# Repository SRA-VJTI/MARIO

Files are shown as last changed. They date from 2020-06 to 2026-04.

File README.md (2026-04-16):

# MARIO WORKSHOP 2.4








*MARIO* abbreviation for *Manipulator on ROS Based Input Output* is a bot with 3 Degree of Freedom. It consists of two SG90 micro servo and one MG995 metal gear servo motor. The servo motors are placed on base, elbow and shoulder enabling it with 3 Degrees of Freedom.

Given below are instructions for ROS2-Humble and micro-ROS installations. For ROS1 and Rosserial based MARIO, refer to the [following instructions](https://github.com/SRA-VJTI/MARIO/tree/noetic).

## Sneak Peek 

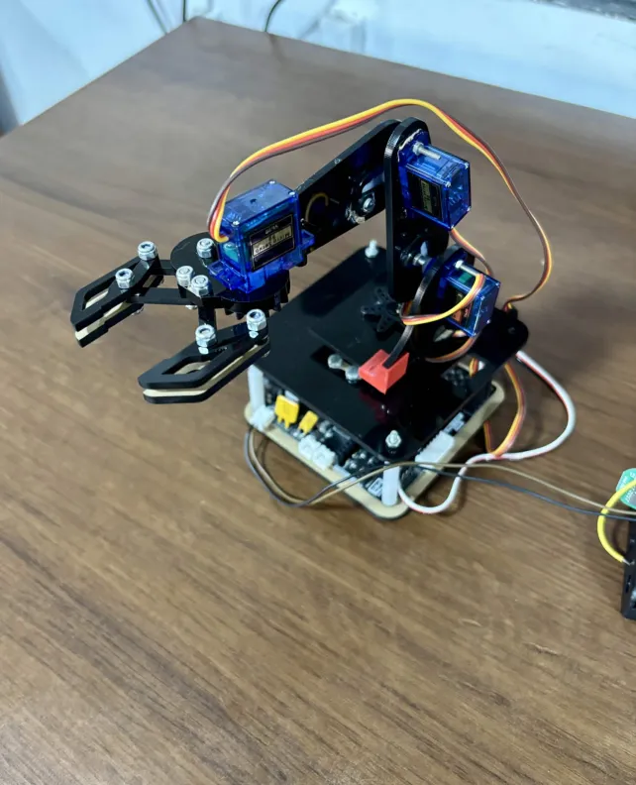
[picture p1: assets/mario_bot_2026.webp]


### Working of the Mario Bot

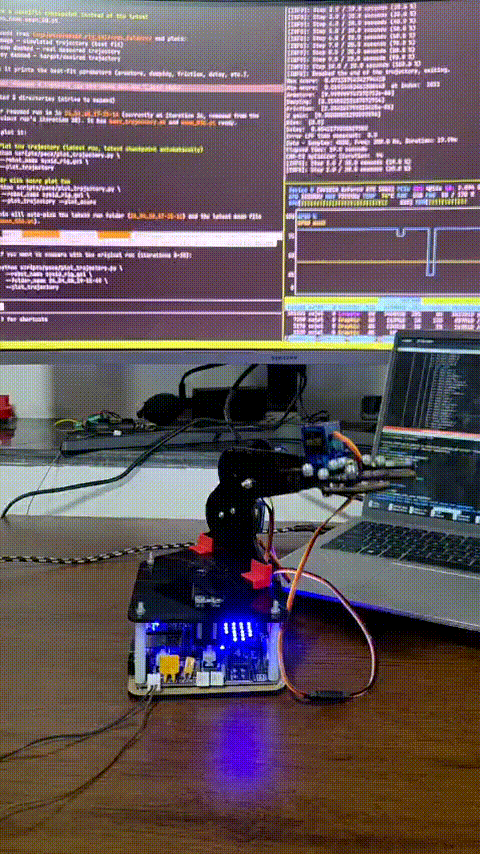
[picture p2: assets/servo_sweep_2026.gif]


### Mario bot simulated using Gazebo

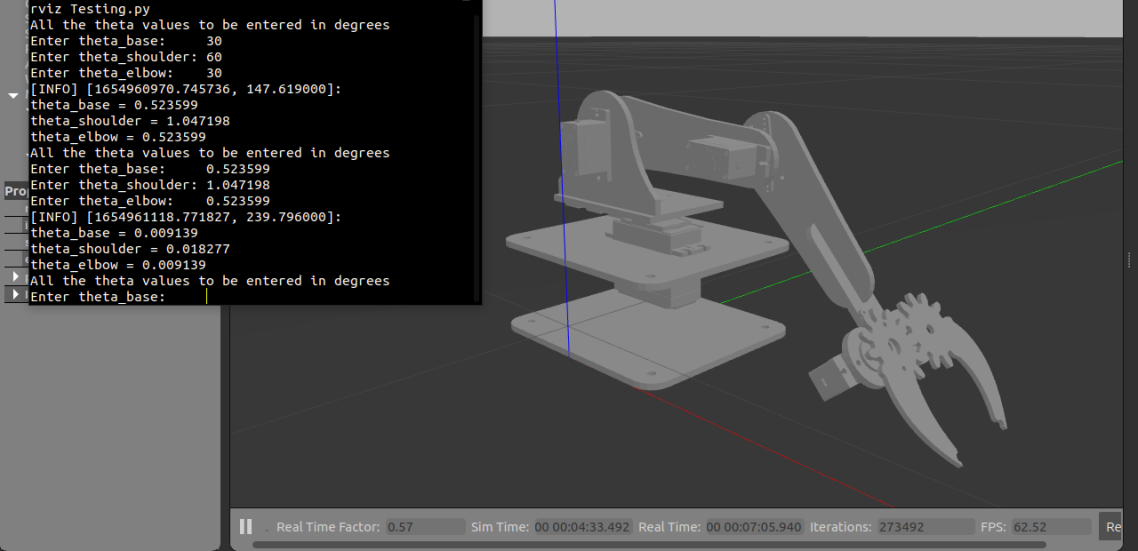
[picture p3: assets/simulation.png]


### Mario bot simulated using Mujoco

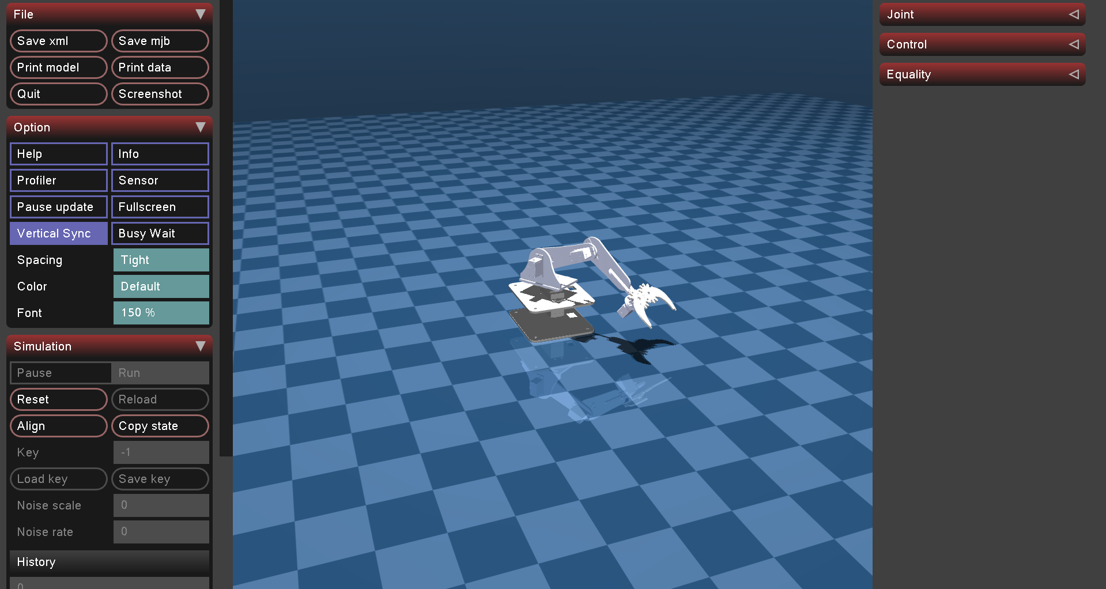
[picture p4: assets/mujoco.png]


## File Structure 
    ├── 1_chatter_listener                        # talker and listener script to understand the nodes and communications in ROS
    ├── 2_simulation_dh                           # simulation of DH parameters
    ├── 3_simulation_rviz                         # simulation of MARIO bot on rviz
    ├── 4_simulation_gazebo                       # simulation of MARIO bot on gazebo
    ├── 5_simulation_mujoco                       # simulation of MARIO bot on mujoco
    ├── assets                                    # contains necessary gifs, images
    ├── firmware                                  # contains ESP-IDF examples for controlling servo motors and micro-ROS
    │   ├── 1_servo_set_ninety                       # example in ESP-IDF to set angles of all servo motor zero
    │   ├── 2_servo_sweep                         # example in ESP-IDF to set variable angles in servo motor
    │   ├── 3_microros_rviz                       # example in ESP-IDF to interface with rviz environment as well as ESP32
    │   ├── 4_microros_gazebo_mujoco                     # example in ESP-IDF to interface with gazebo environment as well as ESP32
    │   ├── 5_servo_test_webserver                # example in ESP-IDF to set angles of servo over the webserver interface
    │   └── components                            # contains all the dependencies required for the above examples
    │       ├── micro_ros_espidf_component        # library to interface between micro-ROS environment and ESP32
    │       └── sra-board-component               # library to interface with SRA board
    ├── LICENSE
    └── README.md 

## Kinematics
* MARIO workshop aims to provide the basic knowledge about the DH parameters, forward kinematics , inverse kinematics.
  * DH Parameters :- Denavit–Hartenberg parameters (also called DH parameters) are the four parameters associated with a particular convention for attaching reference frames to the links of a spatial kinematic chain, or robot manipulator
  * Forward Kinematics :- Forward kinematics refers to the use of the kinematic equations of a robot to compute the position of the end-effector from specified values for the joint parameters. The kinematics equations of the robot are used in robotics, computer games, and animation.
  * Inverse Kinematics :- inverse kinematics is the mathematical process of calculating the variable joint parameters needed to place the end of a kinematic chain, such as a robot manipulator or animation character's skeleton, in a given position and orientation relative to the start of the chain.

## ROS-2 
ROS2 is the ultimate toolkit for robotics enthusiasts and professionals alike. Seamlessly integrating hardware and software, ROS2 streamlines development workflows, accelerates prototyping, and enables rapid iteration. With its modular architecture and extensive library of reusable components, ROS2 simplifies the creation of complex robotics projects, from autonomous drones to collaborative robot arms. 

## Publisher and Subscriber
Publish/Subscribe is a messaging pattern that aims to decouple the sending (Publisher) and receiving (Subscriber) party. A real world example could be a sport mobile app that shows you up-to-date information of a particular football game you're interested in. In this case you are the subscriber, as you express interest in this specific game. On the other side sits the publisher, which is an online reporter that feeds a system with the actual match data.
This system, which is often referred as the message broker brings the two parties together by sending the new data to all interested subscribers.

While ROS2 works on the same system, this system is also used in various other libraries like MQTT.

# MICRO-ROS
micro-ROS is a robotic framework targeting embedded and deep-embedded robot components with extremely constrained computational resources. These devices have special characteristics: a minimum real-time operating system or no operating system, battery-powered, wireless low bandwidth connections, and intermittent operation with sleep periods.

## ESP-IDF
ESP-IDF is the development framework for Espressif SoCs.The [SRA Board](https://github.com/SRA-VJTI/sra-board-hardware-design) uses ESP32 as microcontroller, hence ESPIDF is required
to code the ESP32. Examples included inside firmware directory has been written in ESPIDF version 5.1 .

## Installation of ROS2 and other dependencies 

- Copy and execute the following command in your bash terminal 
```bash
wget -O - https://raw.githubusercontent.com/SRA-VJTI/MARIO/humble/linux_installations.sh | bash
```
- As an alternative, you can also install the required packages on your local machine by following the instructions below.

  - Clone SRA-VJTI's MARIO repository on your system
  ```bash 
  git clone --recursive https://github.com/SRA-VJTI/MARIO.git
  ```
  - Change terminal directory inside the cloned repository
  ```bash
  cd MARIO/
  ```
  - Run the installation script
  ```bash 
  ./linux_installations.sh
  ```

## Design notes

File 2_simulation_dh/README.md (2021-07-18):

## Steps to run the demo in RViz 
We will be running the visualization DH-parameters in RViz.
* First we will be installing the joint_state_publishers and the ros_control for ros-noetic by the following commands

```
sudo apt-get install -y joint-state-publisher
sudo apt-get install ros-noetic-gazebo-ros-pkgs ros-noetic-gazebo-ros-control
```

*  Run the launch file
```
  roslaunch simulation_dh dh_transformation_visualization.launch    
```

<p align="center">
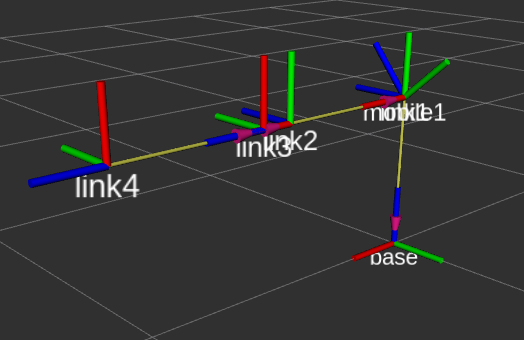
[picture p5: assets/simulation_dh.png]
  
</p>

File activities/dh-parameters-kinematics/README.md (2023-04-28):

# Assignment Day 3

Q.1. Make axes according to the rules given in the DH-parameters for the following end-effectors and bots

Identify the joints and axes in the following bot

Your answer should specify the following parameters:

* Number of joints
* Degrees of freedom
* Types of Joints
* Name all the links starting from base link => search what is ground link
* **Transformation Matrix** from **base to link1 only** => take reference from the DH-parameter’s PPT
* Bonus points if you define your own way of defining DH-parameters 😉

MARIO

```
Note: The lower most link is immovable constraining the workspace of the bot in a single plane
```

Q.2. For the following Robotic arm diagram, Find the DH parameters and the final transformation matrix through Forward Kinematics.



Want a hint ?

`
→ revise ppt (Steps to calculate DH parameter and a particular equation in ppt)
`

Want more hints ?

`→ Ask your seniors :)`

All the best :-)

<!--Q.1. by Alqama and 2 by Chinmay
  SRA-VJTI/MARIO
  Licences for this readme is being transfered solely to the organisation of SRA-VJTI-->

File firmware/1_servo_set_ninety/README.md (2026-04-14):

# Servo Set Ninety

This example demonstrates how to set all servos to 90 degrees for ease of assembly.

## Prerequisites

- ESP-IDF development environment installed and configured
- ESP32 development board
- USB cable for flashing

## Building and Flashing

1. Navigate to the project directory:
   ```bash
   cd ros2_ws_firmware/1_servo_set_ninety
   ```

2. Source the ESP-IDF environment (if not already done):
   ```bash
   # Option 1
   get_idf

   # Option 2
   source . ./esp/esp-idf/export.sh
   ```

3. Build the project:
   ```bash
   idf.py build
   ```

4. Flash to ESP32:
   ```bash
   idf.py -p PORT flash
   ```
   Replace `PORT` with your ESP32's serial port (e.g., `/dev/ttyUSB0` on Linux or `COM3` on Windows)

## Troubleshooting

If you encounter a `cmake flash error`, try the following:

1. Grant permissions to the serial port:
   ```bash
   sudo chmod 777 /dev/ttyUSB0   # Replace with your port
   ```

2. Flash again:
   ```bash
   idf.py -p PORT flash

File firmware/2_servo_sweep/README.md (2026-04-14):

# Servo Sweep Demo

## Overview
This project demonstrates controlling three servos to perform synchronized sweep motions on an ESP32. Each servo moves through different angles in a coordinated pattern.

## Prerequisites
- ESP32 development board
- 3 servo motors connected
- ESP-IDF development environment
- USB cable for flashing

## Hardware Setup
- Ensure all three servos are properly connected to the ESP32
- Check power supply is adequate for all servos
- Verify servo signal pins are connected to correct GPIO pins

## Building and Flashing

1. Navigate to the project directory:
   ```bash
   cd ros2_ws_firmware/2_servo_sweep
   ```

2. Source the ESP-IDF environment:
   ```bash
   # Option 1
   get_idf

   # Option 2
   source $IDF_PATH/export.sh
   ```

3. Build the project:
   ```bash
   idf.py build
   ```

4. Flash to ESP32:
   ```bash
   idf.py -p PORT flash
   ```
   Replace `PORT` with your ESP32's serial port (e.g., `/dev/ttyUSB0` on Linux or `COM3` on Windows)

## Troubleshooting

If you encounter a `cmake flash error`:

1. Set port permissions:
   ```bash
   sudo chmod 777 /dev/ttyUSB0   # Replace with your port
   ```

2. Try flashing again:
   ```bash
   idf.py -p PORT flash
   ```

## Demo

Servo Sweep Demo

## Features
- Synchronized movement of three servo motors
- Smooth sweep motion implementation
- Configurable angle ranges for each servo
- Adjustable sweep speed

## Safety Notes
- Ensure servos are mounted securely
- Keep movement area clear of obstacles
- Monitor servo temperature during extended operation

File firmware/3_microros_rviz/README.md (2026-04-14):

# Micro-ROS with RViz Integration

## Overview
This project demonstrates the integration of ESP32 with RViz using micro-ROS, allowing real-time visualization and control of a robotic manipulator.

## Prerequisites
- ROS 2 installed and configured
- ROS 2 workspace with micro-ROS agent built (`ros2_ws`)
- ESP-IDF development environment
- RViz
- WiFi connection
- `net-tools` package (for network configuration)

## Option 1: WiFi Network

### 1. Start Micro-ROS Agent

Start the micro-ROS agent:
```bash
cd ros2_ws
source install/setup.bash
ros2 run micro_ros_agent micro_ros_agent udp4 --port 8888
```

### 2. Configure and Flash ESP32

1. Navigate to project directory:
   ```bash
   cd ros2_ws_firmware/3_microros_rviz
   ```

2. Source ESP-IDF:
   ```bash
   source $IDF_PATH/export.sh   # Or use 'get_idf' if aliased
   ```

3. Configure WiFi and micro-ROS settings:
   ```bash
   idf.py menuconfig
   ```
   In `micro-ROS Settings`:
   - Set WiFi SSID and Password
   - Configure micro-ROS Agent IP (Find using `ifconfig`)

4. Build and flash:
   ```bash
   idf.py build
   idf.py -p PORT flash    # Replace PORT with your device (e.g., /dev/ttyUSB0)
   ```

### 3. Launch RViz Visualization

1. Navigate to ROS 2 workspace:
   ```bash
   cd ros2_ws
   source install/setup.bash
   ros2 run simulation_rviz rviz.py
   ```

## Option 2: PC Hotspot

If you don't have access to a shared WiFi network, you can create a hotspot from your PC.

### Terminal 1: Create PC Hotspot
```bash
nmcli device wifi hotspot ssid YOUR_HOTSPOT_NAME password "YOUR_PASSWORD" band bg
```

Check the PC's IP address:
```bash
ifconfig
```
The PC hotspot IP is typically `10.42.0.1`.

### Terminal 2: Start Micro-ROS Agent
```bash
cd ros2_ws
source install/setup.bash
ros2 run micro_ros_agent micro_ros_agent udp4 --port 8888 -v6
```

### Terminal 3: Configure and Flash ESP32

1. Navigate to project directory:
   ```bash
   cd ros2_ws_firmware/3_microros_rviz
   ```

2. Source ESP-IDF:
   ```bash
   source $IDF_PATH/export.sh   # Or use 'get_idf' if aliased
   ```

3. Configure settings:
   ```bash
   idf.py menuconfig
   ```
   In `micro-ROS Settings`:
   - WiFi SSID: `YOUR_HOTSPOT_NAME` (must match the hotspot name)
   - WiFi Password: `YOUR_PASSWORD` (must match the hotspot password)
   - Agent IP: `10.42.0.1` (verify with `ifconfig`)
   - Agent Port: `8888`

4. Build and flash:
   ```bash
   idf.py build
   idf.py -p PORT flash
   ```

### Terminal 4: Launch RViz Visualization
```bash
cd ros2_ws
source install/setup.bash
ros2 run simulation_rviz rviz.py
```

> **Note:** If the ESP32 fails to connect, try pressing the reset button on the SRA board after the agent is running.

## Network Configuration

If `ifconfig` command is not found, install net-tools:
```bash
sudo apt install net-tools
```

## Troubleshooting

### Script Execution Issues
If the script isn't executable, set permissions:
```bash
sudo chmod +x rviz.py
```

### Common Issues
- Ensure WiFi connection is stable
- Verify IP addresses are correctly configured
- Check if all terminals are properly sourced
- Confirm micro-ROS agent is running

## Usage
1. Start micro-ROS agent
2. Flash and run ESP32 code
3. Launch RViz visualization
4. Input angles through the publisher interface
5. Observe manipulator movement in RViz

## System Architecture
```
[ESP32] <---> [micro-ROS Agent] <---> [ROS 2] <---> [RViz]
    |            (UDP/IP)           (ROS 2       (Visualization)
    |                               Topics)
 (Hardware
  Control)
```

## Additional Notes
- Ensure all dependencies are installed
- Keep network configuration consistent
- Monitor ESP32 serial output for debugging
- Check ROS 2 topic lists to verify communication

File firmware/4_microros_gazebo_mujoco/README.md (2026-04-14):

# Micro-ROS with Gazebo Integration

## Overview
This project demonstrates how to establish communication between an ESP32 microcontroller and Gazebo simulation environment using micro-ROS, enabling real-time control and visualization of a robotic manipulator.

## Prerequisites
- ROS 2 installed and configured
- Gazebo simulator
- ROS 2 workspace with micro-ROS agent built (`ros2_ws`)
- ESP-IDF development environment
- WiFi connection
- `net-tools` package

## Option 1: WiFi Network

### 1. Launch Micro-ROS Agent

Navigate to micro-ROS workspace and start the agent:
```bash
cd ros2_ws
colcon build
source install/setup.bash
ros2 run micro_ros_agent micro_ros_agent udp4 --port 8888
```

### 2. Configure and Flash ESP32

1. Navigate to project directory:
   ```bash
   cd ros2_ws_firmware/4_microros_gazebo_mujoco
   ```

2. Source ESP-IDF:
   ```bash
   source $IDF_PATH/export.sh   # Or use 'get_idf' if aliased
   ```

3. Configure micro-ROS settings:
   ```bash
   idf.py menuconfig
   ```
   In `micro-ROS Settings`:
   - Configure WiFi SSID and Password
   - Set micro-ROS Agent IP (Find using `ifconfig`)
   - Verify port matches agent configuration (8888)

4. Build and flash:
   ```bash
   idf.py build
   idf.py -p PORT flash    # Replace PORT with your device (e.g., /dev/ttyUSB0)
   ```

### 3. Launch Gazebo Simulation

1. Start Gazebo simulation:
   ```bash
   cd ros2_ws
   source install/setup.bash
   ros2 launch simulation_gazebo basic_gazebo.launch.py
   ```

2. Run kinematics node (in a new terminal):
   ```bash
   cd ros2_ws
   source install/setup.bash
   ros2 run simulation_gazebo forward_kinematics.py
   ```

## Option 2: PC Hotspot

If you don't have access to a shared WiFi network, you can create a hotspot from your PC.

### Terminal 1: Create PC Hotspot
```bash
nmcli device wifi hotspot ssid YOUR_HOTSPOT_NAME password "YOUR_PASSWORD" band bg
```

Check the PC's IP address:
```bash
ifconfig
```
The PC hotspot IP is typically `10.42.0.1`.

### Terminal 2: Start Micro-ROS Agent
```bash
cd ros2_ws
source install/setup.bash
ros2 run micro_ros_agent micro_ros_agent udp4 --port 8888 -v6
```

### Terminal 3: Configure and Flash ESP32

1. Navigate to project directory:
   ```bash
   cd ros2_ws_firmware/4_microros_gazebo_mujoco
   ```

2. Source ESP-IDF:
   ```bash
   source $IDF_PATH/export.sh   # Or use 'get_idf' if aliased
   ```

3. Configure settings:
   ```bash
   idf.py menuconfig
   ```
   In `micro-ROS Settings`:
   - WiFi SSID: `YOUR_HOTSPOT_NAME` (must match the hotspot name)
   - WiFi Password: `YOUR_PASSWORD` (must match the hotspot password)
   - Agent IP: `10.42.0.1` (verify with `ifconfig`)
   - Agent Port: `8888`

4. Build and flash:
   ```bash
   idf.py build
   idf.py -p PORT flash
   ```

### Terminal 4: Launch Simulation and FK Node
```bash
cd ros2_ws
source install/setup.bash
ros2 launch simulation_gazebo basic_gazebo.launch.py
```

In a new terminal:
```bash
cd ros2_ws
source install/setup.bash
ros2 run simulation_gazebo forward_kinematics.py
```

> **Note:** If the ESP32 fails to connect, try pressing the reset button on the SRA board after the agent is running.

## Network Configuration

If `ifconfig` is not available, install net-tools:
```bash
sudo apt install net-tools
```

## System Architecture
```
[ESP32] <---> [micro-ROS Agent] <---> [ROS 2] <---> [Gazebo]
    |            (UDP/IP)           (ROS 2       (Physics
    |                               Topics)       Simulation)
 (Hardware
  Control)
```

## Troubleshooting

### Common Issues
- Verify WiFi connection is stable
- Check IP address configuration
- Ensure all terminals are properly sourced
- Confirm micro-ROS agent is running
- Verify Gazebo simulation launched successfully

### Port Access Issues
If you encounter permission issues:
```bash
sudo chmod 777 /dev/ttyUSB0   # Replace with your port
```

## Usage
1. Launch micro-ROS agent
2. Configure and flash ESP32
3. Start Gazebo simulation
4. Run kinematics node
5. Input joint angles to control the manipulator

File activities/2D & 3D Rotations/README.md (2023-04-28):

## 2D & 3D Rotations

## Questions based on 2D Rotations

Q.1. If A (2, 3) is rotated in the clockwise direction by 90 degrees, what are the coordinate values?

Q.2. If B (1, -2) is rotated in the counterclockwise direction by 60 degrees, what are the coordinate values?

## Questions based on 3D Rotations

Q.1. If A (5, 2, 6) is rotated in the counterclockwise direction by 180 degrees about the x-axis, what are the coordinate values?

Q.2. If B (1, 4, -3) is rotated in the counterclockwise direction by 180 degrees about the x-axis, and then in clockwise direction by 90 degrees in y-axis, what are the coordinate values?

## Hints

Refer the formulas for rotation matrices in 2D and 3D 

All the best !!!

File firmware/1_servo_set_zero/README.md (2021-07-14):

# Servo Set Zero

This example describe how to set all three servos at zero degree angle 

## Steps to follow

* Build and Flash the code 
    * ```cd firmware/servo_set_zero```
    * ```idf.py build```
    * ```idf.py -p PORT flash```

Note :- If it shows ```cmake flash error```. Run the following commands
    * ```sudo chmod 777 PORT```
    * ```idf.py -p PORT flash```

* Demo

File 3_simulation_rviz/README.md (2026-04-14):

## Steps to run the demo in RViz
Introduction to RViz 2:

RViz 2 is a powerful 3D visualization tool provided by the Robot Operating System (ROS) 2 ecosystem. It serves as an essential component for roboticists, engineers, and researchers to visualize and interact with robot models, sensor data, and other important information in a simulated or real-world environment. RViz 2 offers a user-friendly interface with a wide range of features tailored to support the development, debugging, and testing of robotic systems.Here , along we can visualize the URDF of manipulator on Rviz using command line as well as GUI to give input.

* Remember : Whenever you are using ros commands in another terminal , make sure you  source the ros commands:
```
source install/setup.bash
```

*  Run the launch file
```
  ros2 launch simulation_rviz display.launch.py
```

<p align="center">
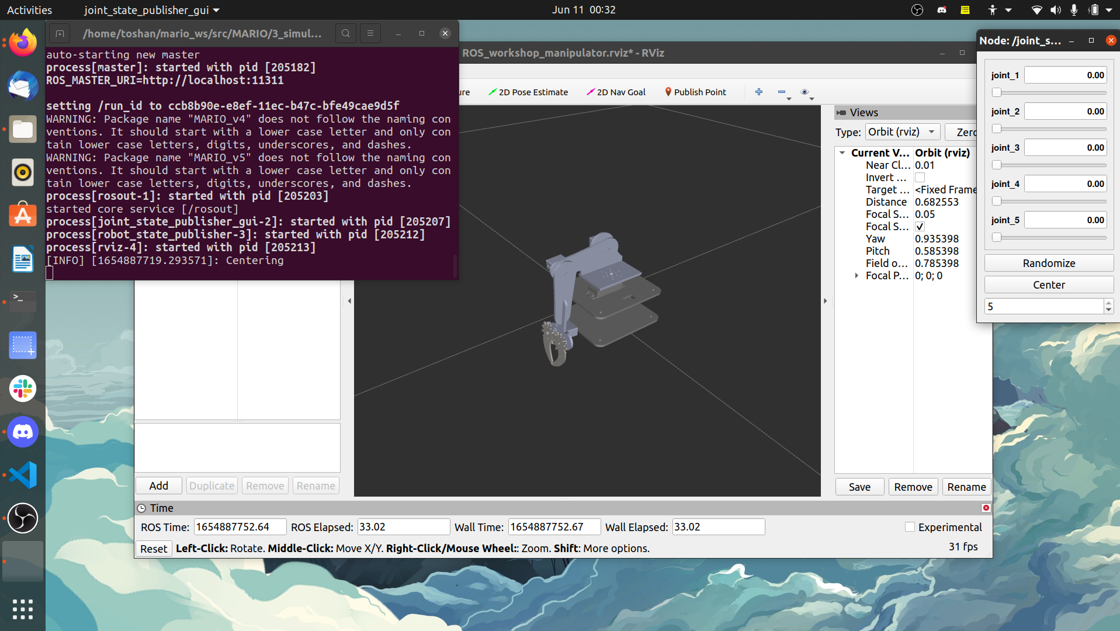
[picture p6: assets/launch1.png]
  
</p>

   *  If you come across this error
Could not find the GUI, install the 'joint_state_publisher_gui' package
   *  Install  using
sudo apt install ros-<your_version_of_ros>-joint-state-publisher-gui
   * Install all the packages required in the same way if needed.

 ----------------------------------------------------------------------

*  Once you are done with the visualisation with gui , Ctrl+ c to stop this .

*  For command line input

```
ros2 launch simulation_rviz rviz.launch.py
```
* To give input angles from command line
```
ros2 run simulation_rviz rviz.py
```

*you can use this command to view the topics actively published. This will show if the values are published to the topic we want to.
```
ros2 topic list
```
*To observe the published data in another terminal
```
ros2 topic echo
```
Then initially set all values to zero , to get the default position of the manipulator .
After this you can now check for different values.

As you give the input in the terminal , you can observe how the manipulator moved according to your input values of angles between links.

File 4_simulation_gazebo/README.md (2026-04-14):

# Table of Contents
* [Steps to run the demo in Gazebo](#steps-to-run-the-demo-in-gazebo)
* [Steps For Running the Scripts in Gazebo](#steps-for-running-the-scripts-in-gazebo)

## Steps to run the demo in Gazebo
* Gazebo is the simulation tool that is used by ROS. It has a lot of Applications. In this workshop we will be using ROS to simulate the Manipulator. For the running the simulation just follow commands mentioned below.
*  Run the launch file

Make sure you have sourced your workspace before running this command.
```
  ros2 launch simulation_gazebo basic_gazebo.launch.py
```

To source your workspace follow the steps mentioned below.
<p align="center">
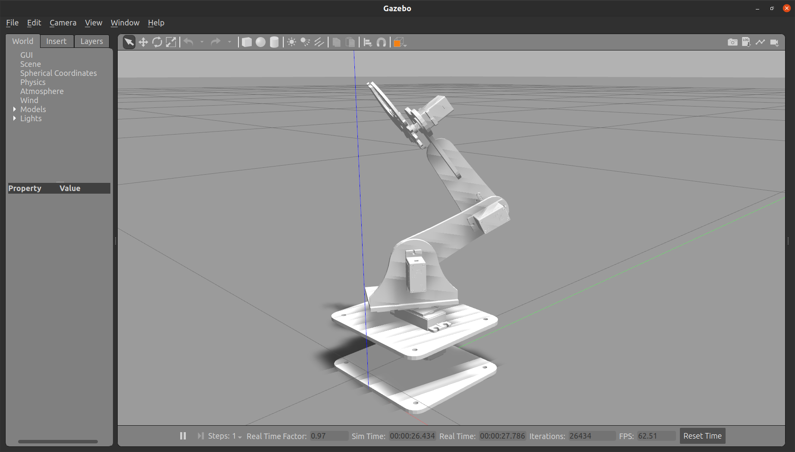
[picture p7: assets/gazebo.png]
  
</p>

### Steps For Running the Scripts in Gazebo
We will be testing out 2 scripts (forward_kinematics.py, inverse_kinematics.py).

Source Ros2. Use following commands in your workspace :

```
source /opt/ros/humble/setup.bash
```
Now we build simulation_gazebo package using this command:

```
colcon build
```
Now we source the workspace using following command :
```
source install/setup.bash
```
For running the scripts on gazebo, firstly launch gazebo world using the command

```
ros2 launch simulation_gazebo basic_gazebo.launch.py
```

After starting gazebo we will be testing out `forward_kinematics.py`.
Open a fresh terminal and navigate to your workspace. Now source the workspace and run forward_kinematics.py using following commands :

```
source install/setup.bash
ros2 run simulation_gazebo forward_kinematics.py
```
Similarly, you can test out the script for `inverse_kinematics.py`.

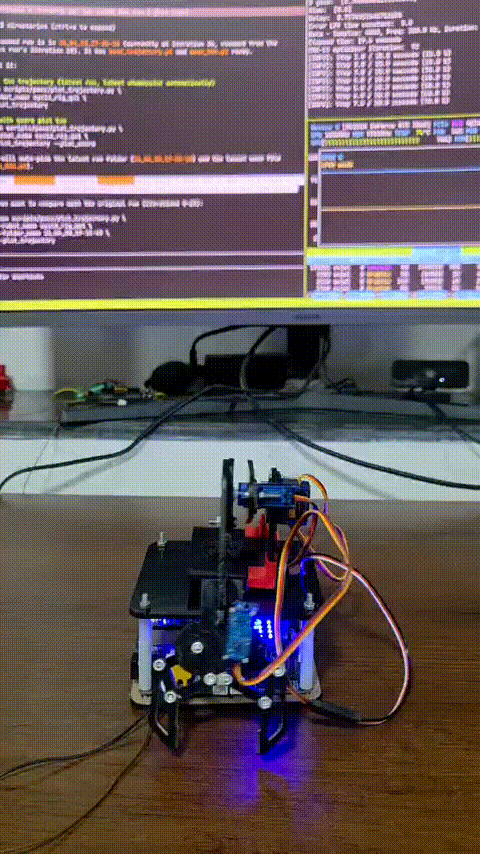
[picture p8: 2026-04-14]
assets/mario_bot_2026.gif

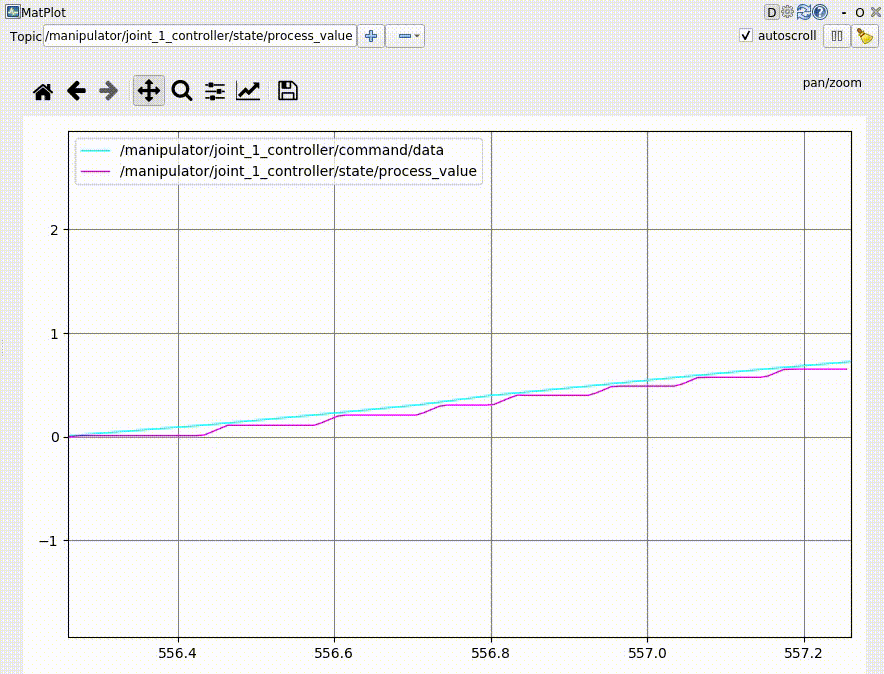
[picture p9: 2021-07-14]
assets/Sin_Wave.gif

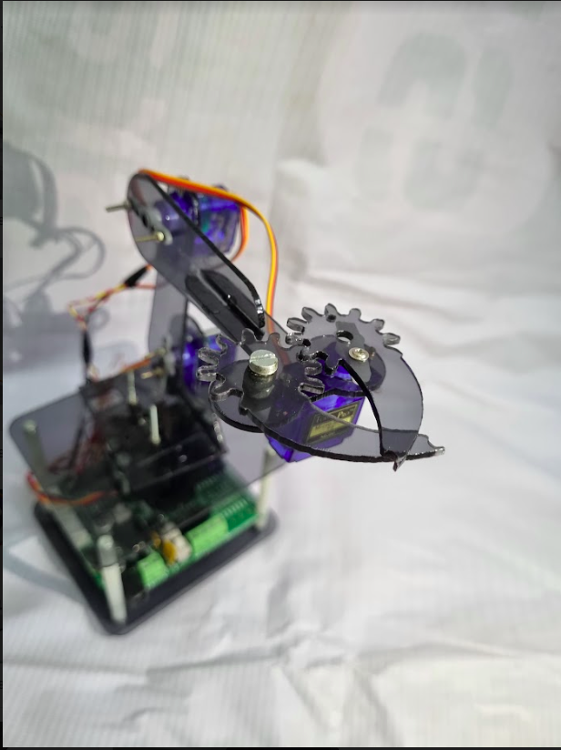
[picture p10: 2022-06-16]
assets/bot2.png

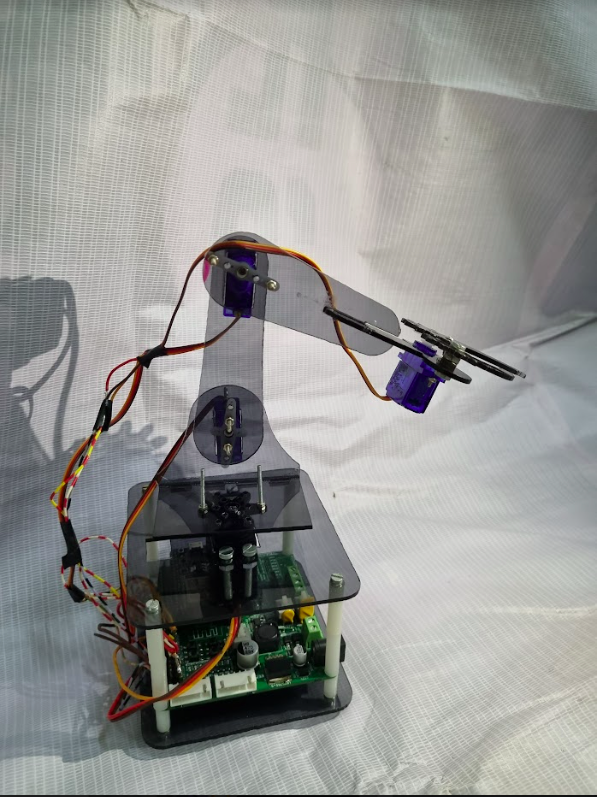
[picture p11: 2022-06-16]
assets/Bot.png

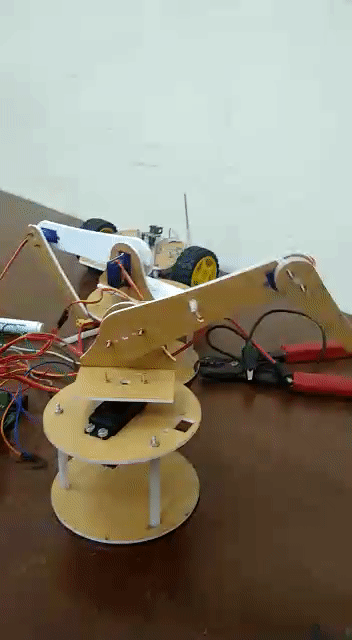
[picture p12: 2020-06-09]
assets/arm.gif

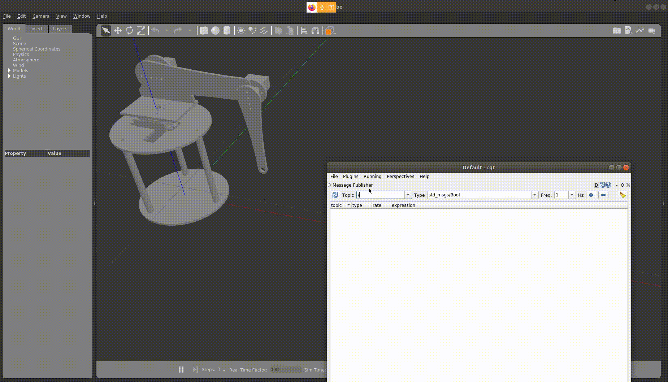
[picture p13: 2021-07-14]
assets/Control_bot.gif

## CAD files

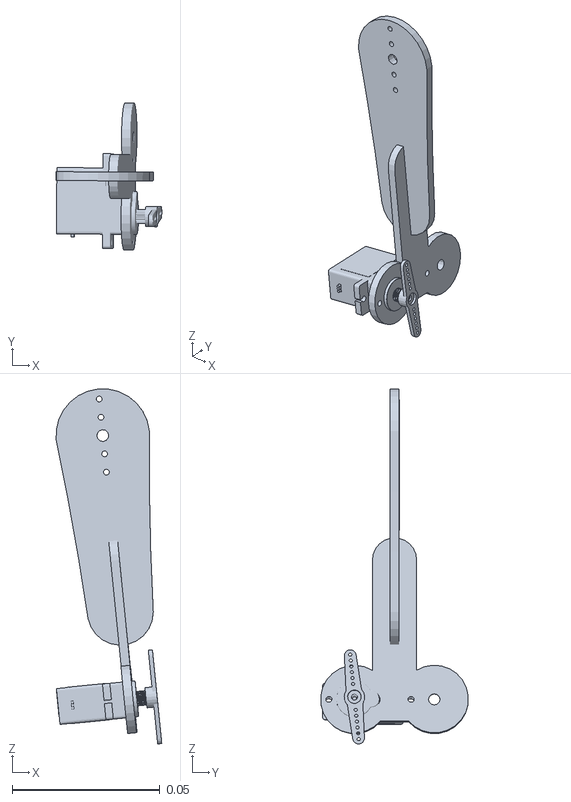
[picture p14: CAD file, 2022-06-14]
5_simulation_mujoco/meshes/link_3.STL
0.0358 x 0.05 x 0.12

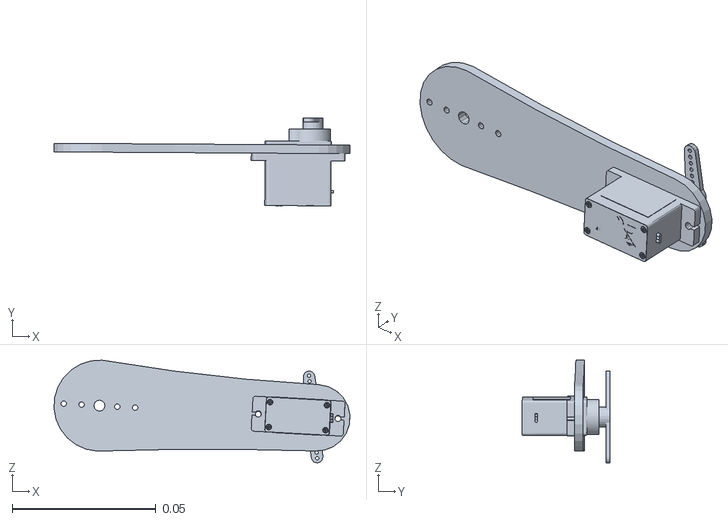
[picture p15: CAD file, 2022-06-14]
5_simulation_mujoco/meshes/link_2.STL
0.103 x 0.0307 x 0.0357

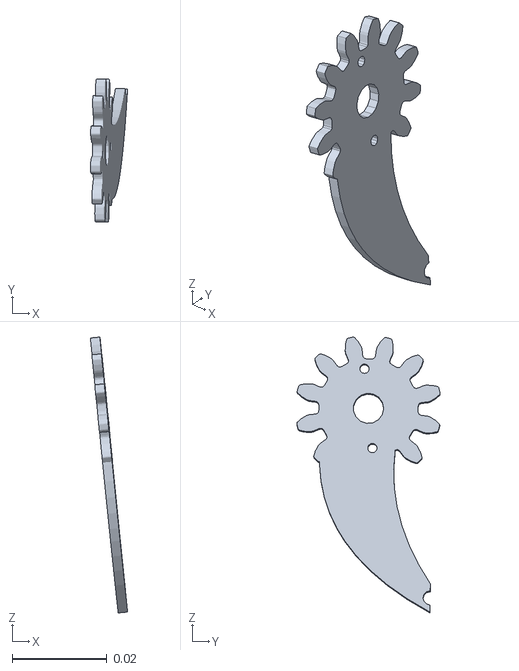
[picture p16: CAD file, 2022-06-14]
5_simulation_mujoco/meshes/claw_right.STL
0.00785 x 0.0302 x 0.0582

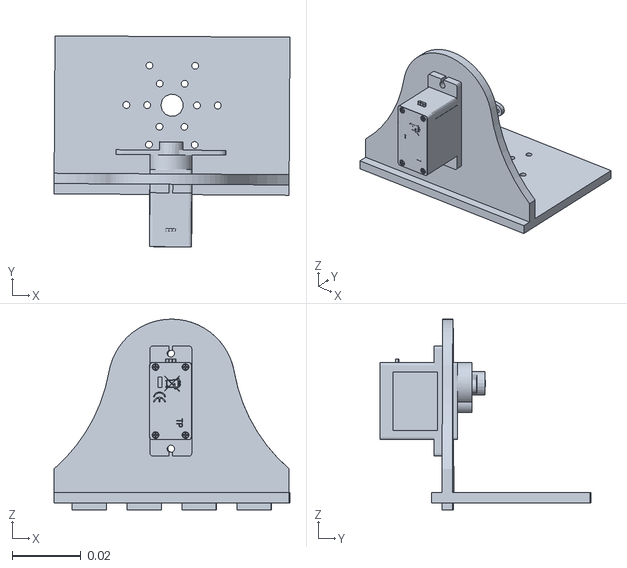
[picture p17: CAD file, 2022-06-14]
5_simulation_mujoco/meshes/link_1.STL
0.0687 x 0.0615 x 0.0555

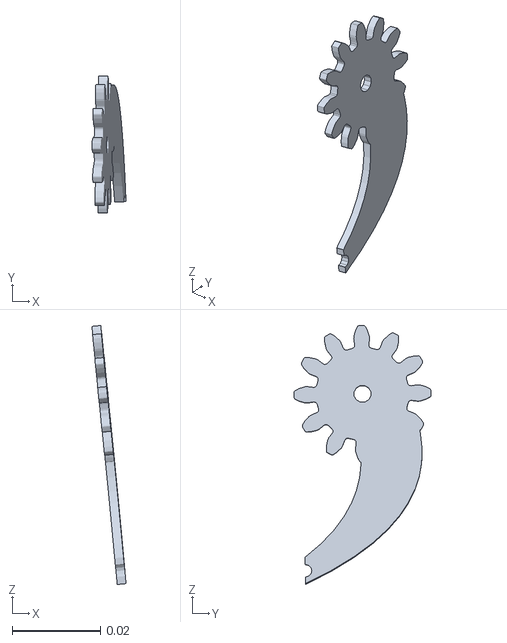
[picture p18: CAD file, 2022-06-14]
5_simulation_mujoco/meshes/claw_left.STL
0.00772 x 0.0309 x 0.0586

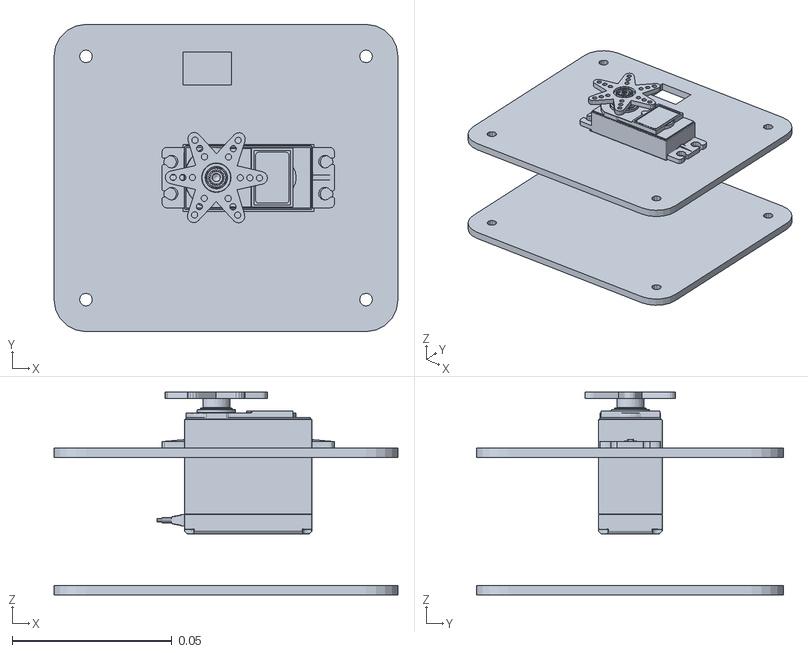
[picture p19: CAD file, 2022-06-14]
5_simulation_mujoco/meshes/base_link.STL
0.108 x 0.0962 x 0.0635

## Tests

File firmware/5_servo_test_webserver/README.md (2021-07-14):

# Servo Test Webserver

This example implements webserver functionality. It provides an easy webpage based User Interface to interact with the servos.

## Steps to follow

* Configure the project
    * ```cd firmware/servo_test_webserver```
    * ```idf.py menuconfig```
    * Inside ```component config -> MARIO testing -> WiFi Config``` set the ssid and password

* Build and Flash the code 
    
    * ```idf.py build```
    * ```idf.py -p PORT flash```

* Monitor the logs
    * ``` idf.py monitor ```

* Access the website using the ```sta ip``` shown on terminal. Simply paste that ```sta_ip``` on browser link section.

Note :- If it shows ```cmake flash error```. Run the following commands
* ```sudo chmod 777 PORT```
* ```idf.py -p PORT flash```

## Demo

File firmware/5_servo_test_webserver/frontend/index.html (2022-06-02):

# MARIO SERVO TESTING

### Servo A

< >

### Servo B

< >

### Servo C

< >

### Servo D

< >

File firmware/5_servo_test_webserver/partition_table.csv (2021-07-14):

# Name | Type | SubType | Offset | Size | Flags
# Note: if you have increased the bootloader size | make sure to update the offsets to avoid overlap
nvs | data | nvs | 0x9000 | 0x6000
phy_init | data | phy | 0xf000 | 0x1000
factory | app | factory | 0x10000 | 1M
www | data | spiffs |  | 1M

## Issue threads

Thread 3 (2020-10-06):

E (21596) esp-ros-wifi: Error receiving data: errno 113 E (22596) esp-ros-wifi: Error receiving data: errno 128

sergera-da-bahia, 2020-10-06:
Hi!
I am trying to reproduce the project from the Workshop, but I'm facing some difficulties when flashing. It shows that the device is connected to the WiFi but I can't stablish any tcp connection.
If someone happens to know, have had the same issue before or have any thoughts on it, it would be very kind and I would be very thankful for it.
The errors from the ESP_LOGS, when monitor using (idf.py monitor) after flashing:

I (1586) esp-ros-wifi: Connected to AP
I (1596) esp-ros-wifi: Successfully connected
E (20596) esp-ros-wifi: Error receiving data: errno 113
E (21596) esp-ros-wifi: Error receiving data: errno 113
E (22596) esp-ros-wifi: Error receiving data: errno 128
E (23596) esp-ros-wifi: Error receiving data: errno 128
E (24596) esp-ros-wifi: Error receiving data: errno 128

The errors seem to be with the socket connection, but I am not any sure of it.
I am flasing the ESP32 using the ESP-IDF on a Windows 10 and ROS Melodic, instead of Linux and ROS Kinetic.
Thanks a lot in Advance to anyone who could have a look on it

VedantParanjape, 2020-10-06:
Hi,

I think there are three reasons for this issue:

1) rosserial node is not running on your PC

2) Windows Firewall is messing up with rosserial stuff

3) You have entered an incorrect ip address in menuconfig.

It would be great if you could post your sdkconfig file here and a screenshot of the following command on windows PC, run it on cmd: `ipconfig/all`

Regards,
_**Vedant Paranjape**_

sergera-da-bahia, 2020-10-07:
Thank you very very much for the fast reply!
If it's in anyway not possible to open the zip files, here are my rosserial configurations in it and than the printscreen of my ipconfig /all

# # rosserial
# CONFIG_ROSSERIAL_OVER_WIFI=y
CONFIG_ROSSERVER_AP="TP-Link_9DB6"
CONFIG_ROSSERVER_PASS="29233213"
CONFIG_ROSSERVER_IP="192.168.0.138"
CONFIG_ROSSERVER_PORT=11411
# end of rosserial
# end of Component config
[sdkconfig.zip](https://github.com/SRA-VJTI/ROS-Workshop-2.1/files/5338872/sdkconfig.zip)

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

VedantParanjape, 2020-10-07:
Hi,

Your Esp side config looks fine. Looking at the error codes,

113 means connection abort: https://github.com/espressif/newlib-esp32/blob/4ddc99d47677b94c115cafcaa4a6939042ea8c4f/newlib/libc/include/sys/errno.h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

and 128 means socket is not connected which is justified since socket connection was aborted above: https://github.com/espressif/newlib-esp32/blob/4ddc99d47677b94c115cafcaa4a6939042ea8c4f/newlib/libc/include/sys/errno.h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

So, I can think of two reasons:

1) You are not running roscore and rosserial. Please attach a screenshot of the following command: `rosnode list`, to check if ros side is working correctly

2) Windows Firewall is blocking the connection, try again by disabling the firewall.

sergera-da-bahia, 2020-10-07:
Yes, that was one issue. I disabled the firewalls and my rosserial_python now finds something at least.
Then, the rosserial before that looked indefinately for a socket connection and never found one, thanks :)

But now I'm becomming those errors
on my ESP_LOGS:
E (7097) esp-ros-wifi: Error receiving data: errno 104
E (8097) esp-ros-wifi: Error receiving data: errno 128

and on my rosserial_python tcp closes automatically the socket:

[INFO] [1602063540.888584]: ROS Serial Python Node
[INFO] [1602063540.901593]: Fork_server is: False
[INFO] [1602063540.901593]: Waiting for socket connections on port 11411
[INFO] [1602063540.901593]: Waiting for socket connection
[INFO] [1602063549.240256]: Established a socket connection from 192.168.0.157 on port 54414
[INFO] [1602063549.255779]: calling startSerialClient
[INFO] [1602063551.362266]: Requesting topics...
[INFO] [1602063551.362266]: Client has exited, closing socket.
[INFO] [1602063551.362266]: Shutting down
[INFO] [1602063551.362266]: All done
Traceback (most recent call last):
  File "C:\Users\...\Documents\rosnoetic_catkin_ws\src\rosserial-noetic-devel\rosserial_python\nodes\serial_node.py", line 72, in <module>
    server.listen()
  File "C:\opt\ros\noetic\x64\lib\site-packages\rosserial_python\SerialClient.py", line 251, in listen
    self.startSerialClient()
  File "C:\opt\ros\noetic\x64\lib\site-packages\rosserial_python\SerialClient.py", line 257, in startSerialClient
    client.run()
  File "C:\opt\ros\noetic\x64\lib\site-packages\rosserial_python\SerialClient.py", line 466, in run
    if self.port.inWaiting() < 1:
  File "C:\opt\ros\noetic\x64\lib\site-packages\rosserial_python\SerialClient.py", line 308, in inWaiting
    chunk = self.socket.recv(1, socket.MSG_DONTWAIT|socket.MSG_PEEK)
AttributeError: module 'socket' has no attribute 'MSG_DONTWAIT'

Since that my rosnode list could only find /rosout
C:\Windows\System32>rosnode list
/rosout

VedantParanjape, 2020-10-07:
104 means connection reset by peer.

I am not sure what causes this issue. Maybe try again, by closing everything and flashing esp32 again.

sergera-da-bahia, 2020-10-07:
Hi,
It worked! Thanks for all the help!
I've followed the error from the link you gave.
https://stackoverflow.com/questions/54071217/attributeerror-module-socket-has-no-attribute-msg-dontwait
And then went further into the topic.
One suggested to set the socket.MSG_DONTWAIT to 0.
In this case in SerialClient.py line 308, in the fuction inWaiting:
chunk = self.socket.recv(1, socket.MSG_DONTWAIT|socket.MSG_PEEK

set to 0:
chunk = self.socket.recv(1, 0|socket.MSG_PEEK)

I am not sure, why it worked. My knowledge in this subject is yet quite limited
But it seemed to be an issue from windows
Again thanks a lot for looking into it

VedantParanjape, 2020-10-07:
Great that it worked, leave a star if you liked it.

> I am not sure, why. My knowledge in this subject is yet quite limited
But it worked :)

It didn't work as, windows networking library doesn't implement MSG_DONTWAIT feature where as linux networking library does, so it's a bug which needs to be fixed by ros guys, the solution is more of a hack. It is better if you use ROS melodic or linux.

sergera-da-bahia, 2020-10-07:
Before the Issue be closed. If I may, I've had a quick question...
I have noticed that it worked perfectly, while the ESP is powered on the USB port from my PC
Whereas when I plug in the power socket on the wall, the rosserial_python hangs by trying to connect to the socket
[INFO] [1602063540.888584]: ROS Serial Python Node
[INFO] [1602063540.901593]: Fork_server is: False
[INFO] [1602063540.901593]: Waiting for socket connections on port 11411
[INFO] [1602063540.901593]: Waiting for socket connection
...
And connects then only, when I plug it back into the USB port from PC..
Is that normal? was it actually intended to work like that? Or am I missing some configuration?

VedantParanjape, 2020-10-07:
> And connects then only, when I plug it back into the USB port from PC..
> Is that normal? was it actually intended to work like that? Or am I missing some configuration?

Whats the power rating of USB Power brick ?

This happens if esp doesn't get enough power, it's wifi fails to work correctly. Try doing this by plugging esp32 in some other PC, which is close to your router.

sergera-da-bahia, 2020-10-08:
Yes that was it. I changed the cable to a newer one and now it worked perfectly!
Again thank you very much!

VedantParanjape, 2020-10-08:
Glad, this project helped you.

:))

sergera-da-bahia, 2020-10-08:
Found directly in Github actually

VedantParanjape, 2020-10-08:
Nice.

I'll close this issue now.

Closed 2020-10-08.

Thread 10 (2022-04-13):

Add gripper support in Simulation

gautam-dev-maker, 2022-04-13:
Since we plan to add gripper in MARIO, we should modify urdf file to make it look similar to real life MARIO.

MOLOCH-dev, 2022-06-15:
Resolved with PRs #14 and #15

Closed 2022-06-15.

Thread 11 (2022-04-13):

Add Gripper support in Real world MARIO.

gautam-dev-maker, 2022-04-13:
With the provision of 4th servo in sra-board-hardware-design, we can add support for a gripper. Hence we need to design a gripper.

gautam-dev-maker, 2022-06-14:
Gripper support has been added, and the design has been thoroughly tested.

Closed 2022-06-14.

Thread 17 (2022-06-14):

Add gripper functionality in firmware/3_rosserial_rviz, firmware/4_rosserial_gazebo

Jamm02, 2022-06-14:

Jamm02, 2022-06-22:
PR sent by @Jash-Shah and successfully merged, issue can be closed.

Closed 2022-06-22.

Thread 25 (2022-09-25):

Update MARIO firmware to latest esp-idf v4.4.

Jamm02, 2022-09-25:

aPR0T0, 2023-04-07:
I think this issue is redundant as another issue focuses on porting it to esp-idf v5.0. :+1:

aPR0T0, 2024-02-08:
As [sra-board-components](https://github.com/SRA-VJTI/sra-board-component) have been migrated successfully to v5.1 so we can close this issue due to lack of relevance

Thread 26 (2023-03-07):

Porting MARIO to ROS2 and esp-idf to 5.0

aPR0T0, 2023-03-07:
- As ROS1 has ended its support for the latest ubuntu versions and as industry is progressing we need to adapt to the changes and port as soon as possible to the ROS2 latest distribution i.e. HUMBLE.
- Same goes for the esp-idf v5.0

Tasks Need to be done
- Porting to ROS2 Humble
- Designing a new end effector (maybe not gripper this time)
- Porting to esp-idf v5.0

aPR0T0, 2024-02-08:
As for the simulator, I have assigned SYs the task for doing the some research and finding which can be a better simulator instead of gazebo.
Options to be considered:
- WeBots
- Gazebo latest (Won't be difficult and most of the code is ready in [this fork](https://github.com/aPR0T0/MARIO/tree/local/dev/3_simulation_gazebo))
- MuJoCo (Overkill for the small task as of MARIO)

Other tasks of porting will be assigned next week.

VedantParanjape, 2024-02-08:
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

Looks good to me, you can implement it and see if it works well and is bug free. Probably do the development in a separate branch.

MOLOCH-dev, 2024-02-08:
Lgtm, a first step would be testing micro-ros with esp32 on ROS2 Humble. Another aspect would be using gz sim Harmonic instead of gazebo classic, I recommend porting the existing URDF to an SDF model. Create separate issues for testing micro-ros/Humble and rviz+ gz sim visualization, mention them in this thread. Update this current issue with a task list.

aPR0T0, 2024-02-10:
Migration from gazebo classic to latest gazebo (harmonic) (#38)

aPR0T0, 2024-02-10:
Migration from rosserial to microros (#39 )

AryanNanda17, 2024-03-21:
Hello @aPR0T0,
- For porting the  [1_chatter_listener](https://github.com/SRA-VJTI/MARIO/tree/master/1_chatter_listener) from ros1_noetic to ros2_humble, should I create a different issue and do pull request and refer that issue or the PR should refer to this issue directly.
- And, in the talker and listener folder, is there any need to add some additional stuff, or only porting is needed.

aPR0T0, 2024-03-21:
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

You can create a separate issue for that
For porting use CMake only for don't use setup.py

AryanNanda17, 2024-03-22:
Alright!

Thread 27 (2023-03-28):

Changing the gripper design

ChinmayMundane, 2023-03-28:
The aim of this issue is to design a new gripper for MARIO.
Older version of MARIO manipulator had an issue with its gripping mechanism. This time, we are thinking of designing new gripper for this purpose.
Currently, There are two designs that we have thought of :

1. Gripper using rack and pinion mechanism :
In this mechanism, gripping is done using rack and pinion structure which is supported/actuated by gear linked with motor.
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

2.  Gripper using more support
This design is similar to the previous one except it has more support which allows it to rotate in a proper manner.

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

aPR0T0, 2023-03-28:
I Think first design is pretty crude so let's first make it feasible first and my suggestion would pe get the hardware in hand of both and then compare which will be better

Jamm02, 2023-03-28:
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

This design is not economical, keeping the costs in mind the designs should include minimum number of parts.

marck3131, 2023-03-28:
The older version had issues with the loose end / the driven gear, you can redesign the same with additional support.
The 1st one can only grab objects perpendicular / and as Alqama already mentioned that the sliding length is too short to grasp other objects.
For the 2nd one, not mainly the gripper will cost more, but because of such design , you might have to redesign the other joints too, which would then be cost effective altogether, but you can go ahead by making a few changes and having a prototype in hand and test.

aPR0T0, 2023-03-29:
> This design is not economical, keeping the costs in mind the designs should include minimum number of parts.

@Jamm02 I don't think cost will be very high for this design, it has small links so should be feasible

Jamm02, 2023-03-30:
> > This design is not economical, keeping the costs in mind the designs should include minimum number of parts.
>
> @Jamm02 I don't think cost will be very high for this design, it has small links so should be feasible

Make a prototype and provide a cost breakdown for the same.
Be ready with atleast two bot prototypes by 10th April.

ChinmayMundane, 2023-04-23:
https://user-images.githubusercontent.com/109454803/233845934-c9d04851-fe0d-416c-b893-c2478196c231.mp4

The issue has been resolved.

Closed 2023-04-23.

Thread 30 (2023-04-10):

Update installer script to install ROS2 and esp-idf v4.4

advait-0, 2023-04-10:
The current installer script needs to be updated to install ROS2 "Humble Hawksbill" and esp-idf v4.4, taking into account all the dependencies.

aPR0T0, 2024-02-10:
@advait-0 as sra-board-components have already been migrated to esp-idf v5.1, so you can restate the motive of this issue accordingly

NachtSpyder04, 2024-02-28:
If possible, can we update the script in such a way that all installations should be done when script is executed only once.
Personally, I feel like running the same script twice for installation doesn't look good and can be confusing for juniors

aPR0T0, 2024-02-28:
Hello @NachtSpyder04 , thanks for your concern. As we are porting now to ros2, we don't need to setup mambaforge environment. And there won't be the issue of running the script twice.

AryanNanda17, 2024-03-21:
Hello @aPR0T0,
Could you please assign this issue to me?
To make sure we are on the same page, could you please answer these questions:-
- The installation script should setup ros2 humble desktop  by following [these](https://docs.ros.org/en/humble/Installation/Alternatives/Ubuntu-Development-Setup.html) instructions and gazebo and it should create a ros2_ws and clone the repo inside it, right?
- The bash script should be created only for Linux users or for both Linux and MacOS? If both, then could you please share the installation guide for macOS users.

AryanNanda17, 2024-03-22:
Parallels Desktop is paid, UTM is a better option.
Your answers are clear to me!
Please assign this issue to me.

aPR0T0, 2024-03-23:
Good Luck with task!

AryanNanda17, 2024-03-25:
@aPR0T0,
For Mac users, should we go with the docker setup?
UTM has so many issues with running the gazebo.

AryanNanda17, 2024-03-25:
I can make a Dockerfile with the requirements.

SuperChamp234, 2024-03-25:
@AryanNanda17 go ahead with a docker setup. Make sure to include MicroROS in it as well.

aPR0T0, 2024-03-25:
Important packages:
1. Ros2 control all packages
2. Gazebo ros2 control
3. Joint state publisher
4. Joint state publisher gui
5. Gazebo classic
6. Controller manager

AryanNanda17, 2024-04-08:
Hello @aPR0T0,
Could you please tell me if I am missing something in the installation script [here](https://gist.github.com/AryanNanda17/ecfee629cd5286447e1e9f2b6c33454d).

aPR0T0, 2024-04-08:
Put the microrosagent in the rosws only

And please add a PR for this, so that review can be in-detail

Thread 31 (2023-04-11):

Porting firmware/5_servo_test_webserver to ROS2 and microROS

SuperChamp234, 2023-04-11:
Currently the `5_servo_test_webserver` uses rosserial, which has been discontinued (as per this closed [issue](https://github.com/ros2/ros2/issues/365)).

The official replacement is [microROS](https://micro.ros.org/docs/overview/hardware/).

I would like to take this issue and port the current implementation to microROD and ROS2.

Closed 2023-04-22.

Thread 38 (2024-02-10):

Migration from Gazebo classis to gazebo harmonic

aPR0T0, 2024-02-10:
[NECESSARY CHANGES]:
- Change URDF to SDF
     -  [Reference](https://answers.gazebosim.org//question/28393/how-to-convert-an-urdf-to-sdf-with-gazebo-ignition/)
     - Things to be considered in this migration
           - While converting directly to .sdf make sure of the controllers from ros2_control
           - First try to understand how the controllers are used in this [example](https://github.com/gazebosim/ros_gz_project_template/tree/main/ros_gz_example_bringup)
           - Clone the above example and try launching rrrobot example and observe the code as it will be helpful for this migration
           - Try using position controllers for the rotational joints
- Rewrite the .launch scripts to .launch.py
    -  For this one can refer this repo [here](https://github.com/aPR0T0/MARIO/tree/local/dev/3_simulation_gazebo)
    - NOTE: This repo works for the gazebo classic with position controllers
- Rewrite the inverse kinematics script for rclpy and utilize position controller to control the joints

[OPTIONAL CHANGES]:
- Writing a smoother angle change for inverse kinematics

[FUTURE PROSPECTS]:
- Writing script for inverse velocity kinematics

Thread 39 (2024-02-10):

Migrating from ROSSERIAL to MICROROS

aPR0T0, 2024-02-10:
ROS1 noetic has an edge-compatible platform rosserial which utilizes its xml-rpc protocol for esp32 and wifi for communication with the roscore. ROS2 on the other hand utilizes DDS as its base protocol, so for this mircoros is a replacement for rosserial.

To be able to successfully migrate firmware of [rosserial_rviz](https://github.com/SRA-VJTI/MARIO/tree/master/firmware/3_rosserial_rviz) and [rosserial_gazebo](https://github.com/SRA-VJTI/MARIO/tree/master/firmware/4_rosserial_gazebo) one needs to go through the following:
1. https://micro.ros.org/docs/tutorials/core/first_application_rtos/freertos/
2. Tutorial on how to write nodes and subscribers for [esp32 microros](https://micro.ros.org/docs/tutorials/programming_rcl_rclc/pub_sub/)
3. Learn commands for flashing the firmware

Re-write details:
1. Subscribe to the common topic of joint angles from the inverse kinematics script
2. Utilize these values and just call servo functions from sra board components

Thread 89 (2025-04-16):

Track removal of CH340 driver workaround (Ubuntu 22.04)

vovw, 2025-04-16:
## Description:

Temporary workaround added for CH340 USB-to-Serial devices on Ubuntu 22.04 in [linux_install.sh](https://github.com/SRA-VJTI/MARIO/blob/humble/linux_install.sh):

Installs patched driver from [Vishal-Mutha/ch340-ubuntu-22.04-fix](https://github.com/Vishal-Mutha/ch340-ubuntu-22.04-fix)
Optionally removes brltty to avoid USB conflicts

This was needed because CH340-based devices (ESP32) were not being recognized correctly (/dev/ttyUSB* missing).

To Do (Later):

- [ ] Monitor Ubuntu updates or upstream kernel support for CH340
- [ ] Confirm whether issue is resolved without the workaround
- [ ] Remove CH340 fix block from linux_install.sh
- [ ] Update README and documentation accordingly

Linked PR: #88

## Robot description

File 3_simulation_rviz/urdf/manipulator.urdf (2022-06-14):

<?xml version="1.0" encoding="utf-8"?>
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
<robot name="manipulator">
  <link name="world">
   </link>
  <link name="base_link">
    <inertial>
      <origin xyz="0.0021253 0.047935 0.027764" rpy="0 0 0" />
      <mass value="0.0896" />
      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
    </inertial>
    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
  </link>
  <joint name="dummy_joint" type="fixed">
     <parent link="world"/>
     <child link="base_link"/>
   </joint>
  <link name="link_1">
    <inertial>
      <origin xyz="-0.00017376 -0.015933 0.017371" rpy="0 0 0" />
      <mass value="0.024846" />
      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
    </inertial>
    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
  </link>
  <joint name="joint_1" type="revolute">
    <origin xyz="-0.0030196 0.046937 0.0635" rpy="0 0 0" />
    <parent link="base_link" />
    <child link="link_1" />
    <axis xyz="0 0 1" />
    <limit lower="0" upper="3.14" effort="1.0" velocity="1.0" />
  </joint>
  <link name="link_2">
    <inertial>
      <origin xyz="0.05189 -0.0024721 -0.0024701" rpy="0 0 0" />
      <mass value="0.01633" />
      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
    </inertial>
    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
  </link>
  <joint name="joint_2" type="revolute">
    <origin xyz="0.00031511 -0.0095653 0.034407" rpy="0 0 0" />
    <parent link="link_1" />
    <child link="link_2" />
    <axis xyz="0 -1 0" />
    <limit lower="0" upper="3.14" effort="1" velocity="1" />
  </joint>
  <link name="link_3">
    <inertial>
      <origin xyz="0.0037357 -0.001707 -0.066045" rpy="0 0 0" />
      <mass value="0.019923" />
      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
    </inertial>
    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
  </link>
  <joint name="joint_3" type="revolute">
    <origin xyz="0.071531 0.011279 -0.0041348" rpy="0 0 0" />
    <parent link="link_2" />
    <child link="link_3" />
    <axis xyz="0 -1 0" />
    <limit lower="0" upper="3.14" effort="1" velocity="1" />
  </joint>
  <link name="claw_right">
    <inertial>
      <origin xyz="0.0018122 0.0028283 -0.0079472" rpy="0 0 0" />
      <mass value="0.013225" />
      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
    </inertial>
    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
  </link>
  <joint name="joint_4" type="revolute">
    <origin xyz="0.020925 -0.013767 -0.090331" rpy="0 0 0" />
    <parent link="link_3" />
    <child link="claw_right" />
    <axis xyz="-1 0 0" />
    <limit lower="0" upper="0.8" effort="1.0" velocity="1.0" />
  </joint>
  
  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

  <link name="claw_left">
    <inertial>
      <origin xyz="0.013771 0.012345 -0.01495" rpy="0 0 0" />
      <mass value="0.013641" />
      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
    </inertial>
    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
  </link>

  <joint name="joint_5" type="revolute">
    <origin xyz="0.0091023 0.0182709 -0.090512" rpy="0 0 0" />
    <parent link="link_3" />
    <child link="claw_left" />
    <axis xyz="1 0 0" />
    <limit lower="0" upper="0.8" effort="1.0" velocity="1.0" />
  </joint>

  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 
</robot>

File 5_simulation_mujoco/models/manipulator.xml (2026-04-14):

<mujoco model="manipulator">
  <compiler angle="radian" meshdir="../meshes" autolimits="true"/>
  
  <option timestep="0.001" gravity="0 0 -9.81">
    <flag warmstart="enable"/>
  </option>
  
  <visual>
    <headlight diffuse="0.6 0.6 0.6" ambient="0.3 0.3 0.3" specular="0 0 0"/>
    <rgba haze="0.15 0.25 0.35 1"/>
    <global azimuth="120" elevation="-20"/>
    <quality shadowsize="4096"/>
    <map stiffness="700" shadowscale="0.5" fogstart="10" fogend="15" zfar="40"/>
  </visual>
  
  <asset>
    <texture name="grid" type="2d" builtin="checker" width="512" height="512" rgb1="0.1 0.2 0.3" rgb2="0.2 0.3 0.4"/>

    <!-- Inc. texrepeat for smaller grid size  -->
    <material name="grid" texture="grid" texrepeat="16 16" texuniform="true" reflectance="0.2"/>

    <texture name="skybox" type="skybox" builtin="gradient" rgb1="0.3 0.5 0.7" rgb2="0.0 0.0 0.0" width="512" height="3072"/>

    <mesh name="base_link" file="base_link.STL" scale="1 1 1"/>
    <mesh name="link_1" file="link_1.STL" scale="1 1 1"/>
    <mesh name="link_2" file="link_2.STL" scale="1 1 1"/>
    <mesh name="link_3" file="link_3.STL" scale="1 1 1"/>
    <mesh name="claw_right" file="claw_right.STL" scale="1 1 1"/>
    <mesh name="claw_left" file="claw_left.STL" scale="1 1 1"/>

    <material name="gray" rgba="0.627 0.627 0.627 1"/>
    <material name="blue" rgba="0.792 0.820 0.933 1"/>
    <material name="silver" rgba="0.776 0.757 0.737 1"/>
  </asset>
  
  <worldbody>
    <light name="spotlight" mode="targetbodycom" target="base_link" directional="false" diffuse="0.8 0.8 0.8" specular="0.3 0.3 0.3" pos="0 0 4.0" dir="0 0 -1" castshadow="true"/>
    <light name="ambient" directional="true" diffuse="0.4 0.4 0.4" specular="0.1 0.1 0.1" pos="0 0 3.0" dir="0 0 -1"/>

    <geom name="floor" type="plane" size="2 2 0.1" material="grid" condim="3"/>

    <body name="base_link" pos="0 0 0.0"> 
      <inertial pos="0.0021253 0.047935 0.027764" mass="0.0896" diaginertia="0.00010836 6.5382E-05 5.041E-05"/>
      <geom type="mesh" mesh="base_link" material="gray" contype="0" conaffinity="0"/>
      <geom type="mesh" mesh="base_link" material="gray" group="1"/>

      <body name="link_1" pos="-0.0030196 0.046937 0.0635">
        <inertial pos="-0.00017376 -0.015933 0.017371" mass="0.024846" diaginertia="7.0045E-06 7.2894E-06 3.4858E-06"/>
        <joint name="joint_1" type="hinge" axis="0 0 1" range="0 3.14" damping="0.1" armature="0.01"/>
        <geom type="mesh" mesh="link_1" material="blue" contype="0" conaffinity="0"/>
        <geom type="mesh" mesh="link_1" material="blue" group="1"/>

        <body name="link_2" pos="0.00031511 -0.0095653 0.034407">
          <inertial pos="0.05189 -0.0024721 -0.0024701" mass="0.01633" diaginertia="5.3932E-06 5.9038E-06 6.549E-07"/>
          <joint name="joint_2" type="hinge" axis="0 -1 0" range="0 3.14" damping="0.1" armature="0.01"/>
          <geom type="mesh" mesh="link_2" material="blue" contype="0" conaffinity="0"/>
          <geom type="mesh" mesh="link_2" material="blue" group="1"/>
          
          <body name="link_3" pos="0.071531 0.011279 -0.0041348">
            <inertial pos="0.0037357 -0.001707 -0.066045" mass="0.019923" diaginertia="1.4011E-06 5.2184E-06 5.6378E-06"/>
            <joint name="joint_3" type="hinge" axis="0 -1 0" range="0 3.14" damping="0.1" armature="0.01"/>
            <geom type="mesh" mesh="link_3" material="blue" contype="0" conaffinity="0"/>
            <geom type="mesh" mesh="link_3" material="blue" group="1"/>
            
            <body name="claw_right" pos="0.020925 -0.013767 -0.090331">
              <inertial pos="0.0018122 0.0028283 -0.0079472" mass="0.013225" diaginertia="5.8458E-07 2.7116E-06 3.2338E-06"/>
              <joint name="joint_4" type="hinge" axis="-1 0 0" range="0 0.8" damping="0.05" armature="0.005"/>
              <geom type="mesh" mesh="claw_right" material="silver" contype="0" conaffinity="0"/>
              <geom type="mesh" mesh="claw_right" material="silver" group="1"/>
            </body>
            
            <body name="claw_left" pos="0.0091023 0.0182709 -0.090512">
              <inertial pos="0.013771 0.012345 -0.01495" mass="0.013641" diaginertia="6.6306E-07 2.8184E-06 3.4175E-06"/>
              <joint name="joint_5" type="hinge" axis="1 0 0" range="0 0.8" damping="0.05" armature="0.005"/>
              <geom type="mesh" mesh="claw_left" pos="0 -0.014 0.0075" material="silver" contype="0" conaffinity="0"/>
              <geom type="mesh" mesh="claw_left" pos="0 -0.014 0.0075" material="silver" group="1"/>
            </body>
          </body>
        </body>
      </body>
    </body>
  </worldbody>
  
  <actuator>
    <position name="joint_1_actuator" joint="joint_1" kp="170" kv="1" ctrlrange="0 3.14"/>
    <position name="joint_2_actuator" joint="joint_2" kp="40" kv="1" ctrlrange="0 3.14"/>
    <position name="joint_3_actuator" joint="joint_3" kp="30" kv="1" ctrlrange="0 3.14"/>
    <position name="joint_4_actuator" joint="joint_4" kp="10" kv="1" ctrlrange="0 0.8"/>
    <position name="joint_5_actuator" joint="joint_5" kp="10" kv="1" ctrlrange="0 0.8"/>
  </actuator>
  
  <sensor>
    <jointpos name="joint_1_pos" joint="joint_1"/>
    <jointpos name="joint_2_pos" joint="joint_2"/>
    <jointpos name="joint_3_pos" joint="joint_3"/>
    <jointpos name="joint_4_pos" joint="joint_4"/>
    <jointpos name="joint_5_pos" joint="joint_5"/>
    
    <jointvel name="joint_1_vel" joint="joint_1"/>
    <jointvel name="joint_2_vel" joint="joint_2"/>
    <jointvel name="joint_3_vel" joint="joint_3"/>
    <jointvel name="joint_4_vel" joint="joint_4"/>
    <jointvel name="joint_5_vel" joint="joint_5"/>
  </sensor>
</mujoco>

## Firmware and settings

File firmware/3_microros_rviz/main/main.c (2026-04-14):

/*
MIT License

Copyright (c) 2024 Society of Robotics and Automation

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
THE SOFTWARE IS PROVIDED "AS IS", WITHOUT WARRANTY OF ANY KIND, EXPRESS OR
IMPLIED, INCLUDING BUT NOT LIMITED TO THE WARRANTIES OF MERCHANTABILITY,
FITNESS FOR A PARTICULAR PURPOSE AND NONINFRINGEMENT. IN NO EVENT SHALL THE
AUTHORS OR COPYRIGHT HOLDERS BE LIABLE FOR ANY CLAIM, DAMAGES OR OTHER
LIABILITY, WHETHER IN AN ACTION OF CONTRACT, TORT OR OTHERWISE, ARISING FROM,
OUT OF OR IN CONNECTION WITH THE SOFTWARE OR THE USE OR OTHER DEALINGS IN THE
SOFTWARE.
*/

#include <string.h>
#include <stdio.h>
#include <unistd.h>

#include "freertos/FreeRTOS.h"
#include "freertos/task.h"
#include "esp_log.h"
#include "esp_system.h"
#include "sra_board.h"
#include <uros_network_interfaces.h>
#include <rcl/rcl.h>
#include <rcl/error_handling.h>
#include <sensor_msgs/msg/joint_state.h>
#include <rclc/rclc.h>
#include <rclc/executor.h>

#ifdef CONFIG_MICRO_ROS_ESP_XRCE_DDS_MIDDLEWARE
#include <rmw_microros/rmw_microros.h>
#endif

#define pi 3.141592653589

//defined macros
#define RCCHECK(fn) { rcl_ret_t temp_rc = fn; if((temp_rc != RCL_RET_OK)){printf("Failed status on line %d: %d. Aborting.\n",__LINE__,(int)temp_rc);vTaskDelete(NULL);}}
#define RCSOFTCHECK(fn) { rcl_ret_t temp_rc = fn; if((temp_rc != RCL_RET_OK)){printf("Failed status on line %d: %d. Continuing.\n",__LINE__,(int)temp_rc);}}
#define ARRAY_LEN 200
#define JOINT_DOUBLE_LEN 5

//Declaring variables with their respective data types
rcl_subscription_t subscriber;
sensor_msgs__msg__JointState recv_msg;
char test_array[ARRAY_LEN];

// structs to set up servo configurations
servo_config servo_a = {		//GRIPPER
	.servo_pin = SERVO_A,
	.min_pulse_width = CONFIG_SERVO_A_MIN_PULSEWIDTH,
	.max_pulse_width = CONFIG_SERVO_A_MAX_PULSEWIDTH,
	.max_degree = CONFIG_SERVO_A_MAX_DEGREE,

};

servo_config servo_b = {		//ELBOW
	.servo_pin = SERVO_B,
	.min_pulse_width = CONFIG_SERVO_B_MIN_PULSEWIDTH,
	.max_pulse_width = CONFIG_SERVO_B_MAX_PULSEWIDTH,
	.max_degree = CONFIG_SERVO_B_MAX_DEGREE,

};

servo_config servo_c = {		//ARM
	.servo_pin = SERVO_C,
	.min_pulse_width = CONFIG_SERVO_C_MIN_PULSEWIDTH,
	.max_pulse_width = CONFIG_SERVO_C_MAX_PULSEWIDTH,
	.max_degree = CONFIG_SERVO_C_MAX_DEGREE,

};

servo_config servo_d = {		//BASE
	.servo_pin = SERVO_D,
	.min_pulse_width = CONFIG_SERVO_D_MIN_PULSEWIDTH,
	.max_pulse_width = CONFIG_SERVO_D_MAX_PULSEWIDTH,
	.max_degree = CONFIG_SERVO_D_MAX_DEGREE,

};


// Callback function defined by user, automatically called whenever new message arrives on subscribed topic 
void subscription_callback(const void * msgin)
{
    
     const sensor_msgs__msg__JointState * msg = (const sensor_msgs__msg__JointState *)msgin;
    
    //To display data on terminal
    printf("Received: %lf\n",  msg->position.data[0]);
    printf("Received: %lf\n",  msg->position.data[1]);
    printf("Received: %lf\n",  msg->position.data[2]);
    printf("Received: %lf\n",  msg->position.data[3]);

    //To control motors according to the data
    set_angle_servo(&servo_d,msg->position.data[0]*180/pi);
    set_angle_servo(&servo_c,msg->position.data[1]*180/pi);
    set_angle_servo(&servo_b,msg->position.data[2]*180/pi);
    set_angle_servo(&servo_a,(1.57-msg->position.data[3])*180/pi);
}

void micro_ros_task(void * arg)
{
	//Initialization 
  	memset(test_array,'z',ARRAY_LEN);
	rcl_allocator_t allocator = rcl_get_default_allocator();
	rclc_support_t support;
	enable_servo();
	
	// Create init_options.
	rcl_init_options_t init_options = rcl_get_zero_initialized_init_options();
	RCCHECK(rcl_init_options_init(&init_options, allocator));

#ifdef CONFIG_MICRO_ROS_ESP_XRCE_DDS_MIDDLEWARE
	rmw_init_options_t* rmw_options = rcl_init_options_get_rmw_init_options(&init_options);

	// Static Agent IP and port can be used instead of autodisvery.
	RCCHECK(rmw_uros_options_set_udp_address(CONFIG_MICRO_ROS_AGENT_IP, CONFIG_MICRO_ROS_AGENT_PORT, rmw_options));
	//RCCHECK(rmw_uros_discover_agent(rmw_options));
#endif
	// Setup support structure.
	RCCHECK(rclc_support_init_with_options(&support, 0, NULL, &init_options, &allocator));

	// Create node.
	rcl_node_t node = rcl_get_zero_initialized_node();
	RCCHECK(rclc_node_init_default(&node, "joint_state_sub", "", &support));

	// Create subscriber.
	RCCHECK(rclc_subscription_init_default(
		&subscriber,
		&node,
		ROSIDL_GET_MSG_TYPE_SUPPORT(sensor_msgs, msg, JointState),
		"/joint_states"));


	// Create executor.
	rclc_executor_t executor = rclc_executor_get_zero_initialized_executor();
	RCCHECK(rclc_executor_init(&executor, &support.context, 2, &allocator));
	unsigned int rcl_wait_timeout = 1000;   // in ms
	RCCHECK(rclc_executor_set_timeout(&executor, RCL_MS_TO_NS(rcl_wait_timeout)));

	RCCHECK(rclc_executor_add_subscription(&executor, &subscriber, &recv_msg, &subscription_callback, ON_NEW_DATA));

	// Spin forever.
	rosidl_runtime_c__String string_buffer[JOINT_DOUBLE_LEN];
	recv_msg.name.data = string_buffer;
	recv_msg.name.size = 0;
	recv_msg.name.capacity = JOINT_DOUBLE_LEN;

	for(int i = 0; i < JOINT_DOUBLE_LEN; i++){
			recv_msg.name.data[i].data = (char*) malloc(ARRAY_LEN);
			recv_msg.name.data[i].size = 0;
			recv_msg.name.data[i].capacity = ARRAY_LEN;
			recv_msg.position.data = (double*) malloc(ARRAY_LEN);
			recv_msg.position.size = 0;
			recv_msg.position.capacity = ARRAY_LEN;
			recv_msg.velocity.data = (double*) malloc(ARRAY_LEN);
			recv_msg.velocity.size = 0;
			recv_msg.velocity.capacity = ARRAY_LEN;
	}
	rclc_executor_spin(&executor);

	// Free resources.
	RCCHECK(rcl_subscription_fini(&subscriber, &node));
	RCCHECK(rcl_node_fini(&node));

  	vTaskDelete(NULL);
}

void app_main(void)
{
#if defined(CONFIG_MICRO_ROS_ESP_NETIF_WLAN) || defined(CONFIG_MICRO_ROS_ESP_NETIF_ENET)
    ESP_ERROR_CHECK(uros_network_interface_initialize());
#endif

    //pin micro-ros task in APP_CPU to make PRO_CPU to deal with wifi:
    xTaskCreate(micro_ros_task,
            "uros_task",
            CONFIG_MICRO_ROS_APP_STACK,
            NULL,
            CONFIG_MICRO_ROS_APP_TASK_PRIO,
            NULL);
}

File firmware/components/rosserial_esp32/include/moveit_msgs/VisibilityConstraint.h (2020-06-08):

#ifndef _ROS_moveit_msgs_VisibilityConstraint_h
#define _ROS_moveit_msgs_VisibilityConstraint_h

#include <stdint.h>
#include <string.h>
#include <stdlib.h>
#include "ros/msg.h"
#include "geometry_msgs/PoseStamped.h"

namespace moveit_msgs
{

  class VisibilityConstraint : public ros::Msg
  {
    public:
      typedef double _target_radius_type;
      _target_radius_type target_radius;
      typedef geometry_msgs::PoseStamped _target_pose_type;
      _target_pose_type target_pose;
      typedef int32_t _cone_sides_type;
      _cone_sides_type cone_sides;
      typedef geometry_msgs::PoseStamped _sensor_pose_type;
      _sensor_pose_type sensor_pose;
      typedef double _max_view_angle_type;
      _max_view_angle_type max_view_angle;
      typedef double _max_range_angle_type;
      _max_range_angle_type max_range_angle;
      typedef uint8_t _sensor_view_direction_type;
      _sensor_view_direction_type sensor_view_direction;
      typedef double _weight_type;
      _weight_type weight;
      enum { SENSOR_Z = 0 };
      enum { SENSOR_Y = 1 };
      enum { SENSOR_X = 2 };

    VisibilityConstraint():
      target_radius(0),
      target_pose(),
      cone_sides(0),
      sensor_pose(),
      max_view_angle(0),
      max_range_angle(0),
      sensor_view_direction(0),
      weight(0)
    {
    }

    virtual int serialize(unsigned char *outbuffer) const
    {
      int offset = 0;
      union {
        double real;
        uint64_t base;
      } u_target_radius;
      u_target_radius.real = this->target_radius;
      *(outbuffer + offset + 0) = (u_target_radius.base >> (8 * 0)) & 0xFF;
      *(outbuffer + offset + 1) = (u_target_radius.base >> (8 * 1)) & 0xFF;
      *(outbuffer + offset + 2) = (u_target_radius.base >> (8 * 2)) & 0xFF;
      *(outbuffer + offset + 3) = (u_target_radius.base >> (8 * 3)) & 0xFF;
      *(outbuffer + offset + 4) = (u_target_radius.base >> (8 * 4)) & 0xFF;
      *(outbuffer + offset + 5) = (u_target_radius.base >> (8 * 5)) & 0xFF;
      *(outbuffer + offset + 6) = (u_target_radius.base >> (8 * 6)) & 0xFF;
      *(outbuffer + offset + 7) = (u_target_radius.base >> (8 * 7)) & 0xFF;
      offset += sizeof(this->target_radius);
      offset += this->target_pose.serialize(outbuffer + offset);
      union {
        int32_t real;
        uint32_t base;
      } u_cone_sides;
      u_cone_sides.real = this->cone_sides;
      *(outbuffer + offset + 0) = (u_cone_sides.base >> (8 * 0)) & 0xFF;
      *(outbuffer + offset + 1) = (u_cone_sides.base >> (8 * 1)) & 0xFF;
      *(outbuffer + offset + 2) = (u_cone_sides.base >> (8 * 2)) & 0xFF;
      *(outbuffer + offset + 3) = (u_cone_sides.base >> (8 * 3)) & 0xFF;
      offset += sizeof(this->cone_sides);
      offset += this->sensor_pose.serialize(outbuffer + offset);
      union {
        double real;
        uint64_t base;
      } u_max_view_angle;
      u_max_view_angle.real = this->max_view_angle;
      *(outbuffer + offset + 0) = (u_max_view_angle.base >> (8 * 0)) & 0xFF;
      *(outbuffer + offset + 1) = (u_max_view_angle.base >> (8 * 1)) & 0xFF;
      *(outbuffer + offset + 2) = (u_max_view_angle.base >> (8 * 2)) & 0xFF;
      *(outbuffer + offset + 3) = (u_max_view_angle.base >> (8 * 3)) & 0xFF;
      *(outbuffer + offset + 4) = (u_max_view_angle.base >> (8 * 4)) & 0xFF;
      *(outbuffer + offset + 5) = (u_max_view_angle.base >> (8 * 5)) & 0xFF;
      *(outbuffer + offset + 6) = (u_max_view_angle.base >> (8 * 6)) & 0xFF;
      *(outbuffer + offset + 7) = (u_max_view_angle.base >> (8 * 7)) & 0xFF;
      offset += sizeof(this->max_view_angle);
      union {
        double real;
        uint64_t base;
      } u_max_range_angle;
      u_max_range_angle.real = this->max_range_angle;
      *(outbuffer + offset + 0) = (u_max_range_angle.base >> (8 * 0)) & 0xFF;
      *(outbuffer + offset + 1) = (u_max_range_angle.base >> (8 * 1)) & 0xFF;
      *(outbuffer + offset + 2) = (u_max_range_angle.base >> (8 * 2)) & 0xFF;
      *(outbuffer + offset + 3) = (u_max_range_angle.base >> (8 * 3)) & 0xFF;
      *(outbuffer + offset + 4) = (u_max_range_angle.base >> (8 * 4)) & 0xFF;
      *(outbuffer + offset + 5) = (u_max_range_angle.base >> (8 * 5)) & 0xFF;
      *(outbuffer + offset + 6) = (u_max_range_angle.base >> (8 * 6)) & 0xFF;
      *(outbuffer + offset + 7) = (u_max_range_angle.base >> (8 * 7)) & 0xFF;
      offset += sizeof(this->max_range_angle);
      *(outbuffer + offset + 0) = (this->sensor_view_direction >> (8 * 0)) & 0xFF;
      offset += sizeof(this->sensor_view_direction);
      union {
        double real;
        uint64_t base;
      } u_weight;
      u_weight.real = this->weight;
      *(outbuffer + offset + 0) = (u_weight.base >> (8 * 0)) & 0xFF;
      *(outbuffer + offset + 1) = (u_weight.base >> (8 * 1)) & 0xFF;
      *(outbuffer + offset + 2) = (u_weight.base >> (8 * 2)) & 0xFF;
      *(outbuffer + offset + 3) = (u_weight.base >> (8 * 3)) & 0xFF;
      *(outbuffer + offset + 4) = (u_weight.base >> (8 * 4)) & 0xFF;
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

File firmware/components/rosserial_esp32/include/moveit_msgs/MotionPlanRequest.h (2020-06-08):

#ifndef _ROS_moveit_msgs_MotionPlanRequest_h
#define _ROS_moveit_msgs_MotionPlanRequest_h

#include <stdint.h>
#include <string.h>
#include <stdlib.h>
#include "ros/msg.h"
#include "moveit_msgs/WorkspaceParameters.h"
#include "moveit_msgs/RobotState.h"
#include "moveit_msgs/Constraints.h"
#include "moveit_msgs/TrajectoryConstraints.h"

namespace moveit_msgs
{

  class MotionPlanRequest : public ros::Msg
  {
    public:
      typedef moveit_msgs::WorkspaceParameters _workspace_parameters_type;
      _workspace_parameters_type workspace_parameters;
      typedef moveit_msgs::RobotState _start_state_type;
      _start_state_type start_state;
      uint32_t goal_constraints_length;
      typedef moveit_msgs::Constraints _goal_constraints_type;
      _goal_constraints_type st_goal_constraints;
      _goal_constraints_type * goal_constraints;
      typedef moveit_msgs::Constraints _path_constraints_type;
      _path_constraints_type path_constraints;
      typedef moveit_msgs::TrajectoryConstraints _trajectory_constraints_type;
      _trajectory_constraints_type trajectory_constraints;
      typedef const char* _planner_id_type;
      _planner_id_type planner_id;
      typedef const char* _group_name_type;
      _group_name_type group_name;
      typedef int32_t _num_planning_attempts_type;
      _num_planning_attempts_type num_planning_attempts;
      typedef double _allowed_planning_time_type;
      _allowed_planning_time_type allowed_planning_time;
      typedef double _max_velocity_scaling_factor_type;
      _max_velocity_scaling_factor_type max_velocity_scaling_factor;
      typedef double _max_acceleration_scaling_factor_type;
      _max_acceleration_scaling_factor_type max_acceleration_scaling_factor;

    MotionPlanRequest():
      workspace_parameters(),
      start_state(),
      goal_constraints_length(0), goal_constraints(NULL),
      path_constraints(),
      trajectory_constraints(),
      planner_id(""),
      group_name(""),
      num_planning_attempts(0),
      allowed_planning_time(0),
      max_velocity_scaling_factor(0),
      max_acceleration_scaling_factor(0)
    {
    }

    virtual int serialize(unsigned char *outbuffer) const
    {
      int offset = 0;
      offset += this->workspace_parameters.serialize(outbuffer + offset);
      offset += this->start_state.serialize(outbuffer + offset);
      *(outbuffer + offset + 0) = (this->goal_constraints_length >> (8 * 0)) & 0xFF;
      *(outbuffer + offset + 1) = (this->goal_constraints_length >> (8 * 1)) & 0xFF;
      *(outbuffer + offset + 2) = (this->goal_constraints_length >> (8 * 2)) & 0xFF;
      *(outbuffer + offset + 3) = (this->goal_constraints_length >> (8 * 3)) & 0xFF;
      offset += sizeof(this->goal_constraints_length);
      for( uint32_t i = 0; i < goal_constraints_length; i++){
      offset += this->goal_constraints[i].serialize(outbuffer + offset);
      }
      offset += this->path_constraints.serialize(outbuffer + offset);
      offset += this->trajectory_constraints.serialize(outbuffer + offset);
      uint32_t length_planner_id = strlen(this->planner_id);
      varToArr(outbuffer + offset, length_planner_id);
      offset += 4;
      memcpy(outbuffer + offset, this->planner_id, length_planner_id);
      offset += length_planner_id;
      uint32_t length_group_name = strlen(this->group_name);
      varToArr(outbuffer + offset, length_group_name);
      offset += 4;
      memcpy(outbuffer + offset, this->group_name, length_group_name);
      offset += length_group_name;
      union {
        int32_t real;
        uint32_t base;
      } u_num_planning_attempts;
      u_num_planning_attempts.real = this->num_planning_attempts;
      *(outbuffer + offset + 0) = (u_num_planning_attempts.base >> (8 * 0)) & 0xFF;
      *(outbuffer + offset + 1) = (u_num_planning_attempts.base >> (8 * 1)) & 0xFF;
      *(outbuffer + offset + 2) = (u_num_planning_attempts.base >> (8 * 2)) & 0xFF;
      *(outbuffer + offset + 3) = (u_num_planning_attempts.base >> (8 * 3)) & 0xFF;
      offset += sizeof(this->num_planning_attempts);
      union {
        double real;
        uint64_t base;
      } u_allowed_planning_time;
      u_allowed_planning_time.real = this->allowed_planning_time;
      *(outbuffer + offset + 0) = (u_allowed_planning_time.base >> (8 * 0)) & 0xFF;
      *(outbuffer + offset + 1) = (u_allowed_planning_time.base >> (8 * 1)) & 0xFF;
      *(outbuffer + offset + 2) = (u_allowed_planning_time.base >> (8 * 2)) & 0xFF;
      *(outbuffer + offset + 3) = (u_allowed_planning_time.base >> (8 * 3)) & 0xFF;
      *(outbuffer + offset + 4) = (u_allowed_planning_time.base >> (8 * 4)) & 0xFF;
      *(outbuffer + offset + 5) = (u_allowed_planning_time.base >> (8 * 5)) & 0xFF;
      *(outbuffer + offset + 6) = (u_allowed_planning_time.base >> (8 * 6)) & 0xFF;
      *(outbuffer + offset + 7) = (u_allowed_planning_time.base >> (8 * 7)) & 0xFF;
      offset += sizeof(this->allowed_planning_time);
      union {
        double real;
        uint64_t base;
      } u_max_velocity_scaling_factor;
      u_max_velocity_scaling_factor.real = this->max_velocity_scaling_factor;
      *(outbuffer + offset + 0) = (u_max_velocity_scaling_factor.base >> (8 * 0)) & 0xFF;
      *(outbuffer + offset + 1) = (u_max_velocity_scaling_factor.base >> (8 * 1)) & 0xFF;
      *(outbuffer + offset + 2) = (u_max_velocity_scaling_factor.base >> (8 * 2)) & 0xFF;
      *(outbuffer + offset + 3) = (u_max_velocity_scaling_factor.base >> (8 * 3)) & 0xFF;
      *(outbuffer + offset + 4) = (u_max_velocity_scaling_factor.base >> (8 * 4)) & 0xFF;
      *(outbuffer + offset + 5) = (u_max_velocity_scaling_factor.base >> (8 * 5)) & 0xFF;
      *(outbuffer + offset + 6) = (u_max_velocity_scaling_factor.base >> (8 * 6)) & 0xFF;
      *(outbuffer + offset + 7) = (u_max_velocity_scaling_factor.base >> (8 * 7)) & 0xFF;
      offset += sizeof(this->max_velocity_scaling_factor);
      union {
        double real;
        uint64_t base;
      } u_max_acceleration_scaling_factor;
      u_max_acceleration_scaling_factor.real = this->max_acceleration_scaling_factor;
      *(outbuffer + offset + 0) = (u_max_acceleration_scaling_factor.base >> (8 * 0)) & 0xFF;
      *(outbuffer + offset + 1) = (u_max_acceleration_scaling_factor.base >> (8 * 1)) & 0xFF;
      *(outbuffer + offset + 2) = (u_max_acceleration_scaling_factor.base >> (8 * 2)) & 0xFF;
      *(outbuffer + offset + 3) = (u_max_acceleration_scaling_factor.base >> (8 * 3)) & 0xFF;
      *(outbuffer + offset + 4) = (u_max_acceleration_scaling_factor.base >> (8 * 4)) & 0xFF;
      *(outbuffer + offset + 5) = (u_max_acceleration_scaling_factor.base >> (8 * 5)) & 0xFF;
      *(outbuffer + offset + 6) = (u_max_acceleration_scaling_factor.base >> (8 * 6)) & 0xFF;
      *(outbuffer + offset + 7) = (u_max_acceleration_scaling_factor.base >> (8 * 7)) & 0xFF;
      offset += sizeof(this->max_acceleration_scaling_factor);
      return offset;
    }
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

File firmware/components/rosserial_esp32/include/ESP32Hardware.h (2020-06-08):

#ifndef ROS_ESP32_HARDWARE_H_
#define ROS_ESP32_HARDWARE_H_

extern "C" {
#include "sdkconfig.h"
#include "stdio.h"
#include "esp_err.h"
#include "esp_timer.h"
#include <driver/uart.h>
#include "esp_ros_wifi.h"
}

#define ROS_SERVER_IP       CONFIG_ROSSERVER_IP
#define ROS_SERVER_PORT     CONFIG_ROSSERVER_PORT

#define UART_PORT           UART_NUM_0
#define UART_TX_PIN         GPIO_NUM_1
#define UART_RX_PIN         GPIO_NUM_3

class ESP32Hardware
{
    protected:
        uint8_t rx_buf[1024];

    public:
        ESP32Hardware()
        {
        }

        // Initialization code for ESP32
        void init()
        {
#ifdef CONFIG_ROSSERIAL_OVER_WIFI
            esp_ros_wifi_init();
            ros_tcp_connect(ROS_SERVER_IP, ROS_SERVER_PORT);
#else
            uart_driver_install(UART_PORT, 1024, 1024, 0, NULL, 0);

            //Changing the baudrate will change the baudrate of serial monitor as well
            //uart_set_baudrate(UART_PORT, 57600);
#endif
        }

        // read a byte from the serial port. -1 = failure
        int read()
        {
            int read_len;
#ifdef CONFIG_ROSSERIAL_OVER_WIFI
            read_len = ros_tcp_read(rx_buf, 1);
#else
            read_len = uart_read_bytes(UART_PORT, (uint8_t *)rx_buf, 1, 0);
#endif
            if (read_len == 1) {
                return rx_buf[0];
            } else {
                return -1;
            }
        }

        // write data to the connection to ROS
        void write(uint8_t* data, int length)
        {
#ifdef CONFIG_ROSSERIAL_OVER_WIFI
            ros_tcp_send(data, length);
#else
            uart_write_bytes(UART_PORT, (char*)data, (size_t)length);
#endif
        }

        // returns milliseconds since start of program
        unsigned long time()
        {
            return esp_timer_get_time() / 1000;
        }
};
#endif

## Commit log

2020-02-11 fixed file structure, added local component folder, ported all test codes to idf-v4.x
    [AddTwoInts.h, ESP32Hardware.h, InteractiveMarkerInit.h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]
2020-02-12 ported to geometry_msgs/Vector3 for message type, and ported rosserial_esp32 float64 to 8 bytes, as Vector3 Float64 was having issues
    [AddTwoInts.h, AttachedCollisionObject.h, ContactInformation.h]
2020-02-13 written new code for kinematics and changed message type to geometry_msgs/Vector3
2020-02-13 fixed issue with moveit by merging the functions in a single component file
    [esp_serial.cpp, main.c]
2020-02-14 fixed rviz data transfer issue by removing debug_led() as it had a 100ms delay which slowed the process of recieving data
    [esp_serial.cpp]
2020-03-09 removed catkin_ws and improved fk ik printing
2020-03-11 added code to servo.c to slowdown angle change
2020-03-11 added delay to servo execution
2020-03-11 Changed servo delay
2020-03-11 Added specific servo_control for servo sweep
2020-03-11 Minor fix in servo.h
2020-03-11 Fixed servo sweep
2020-06-08 moved esp32 codes to a folder
2021-07-08 Added simulation files (#5)
    * Added Simulation repository
    * Deleted esp32_codes
    [link_0.STL, link_1.STL, link_2.STL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]
2021-07-08 Added Servo-Sweep and Servo-Net-Zero example code (#4)
    * Added servo_pin in the servo_config struct of the Servo A,B,C
    * Added sra-board-component as submodule
    * Updated Readme.md
2021-07-12 Added servo_test_webserver example
    [partition_table.csv]
2021-07-12 Divided the packages, and updated the ReadME (#7)
    * Divided ROS Packages adn Updated README
    * Divided ROS Packages adn Updated README
    * Divided ROS Packages adn Updated README
    * Updated ReadME
    * Update README.md
    * Update README.md
    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
    [link_0.STL, link_1.STL, link_2.STL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]
2021-07-14 Changed the file structure
    [link_0.STL, link_1.STL, link_2.STL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]
2022-06-02 Add 4th servo support to 5_servo_test_webserver (#13)
    * Add 4th servo support to 5_servo_test_webserver
    Files changed: main/main.c
    main/tuning_http_server.c
    main/tuning_http_server.h
    frontend/index.html
    * Pulled down update to sra-board-component
2022-06-04 Add new model to package, update publishing scripts
    [base_link.STL, claw_left.STL, claw_right.STL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]
2022-06-05 Update .yaml with stable values for joints 4,5
    [manipulator.urdf]
2022-06-05 Add new model for gazebo simulation
    [base_link.STL, claw_left.STL, claw_right.STL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]
2022-06-05 Update model to work within 0 to 180 deg
    [base_link.STL, claw_left.STL, claw_right.STL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]
2022-06-05 Update model for angles between 0 and 180 deg
    [base_link.STL, claw_left.STL, claw_right.STL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]
2022-06-15 Pulled updates from sra-board-components (#19)
    * pulled changes from sra-board-components
    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
2022-06-16 Mario gripper servo functionality added (#12)
    * Adds gripper servo functionality
    * Adds functionality of fourth servo
    * Improved formatting
    * Update main.c
    formatting correted
    * Update main.c
    Correted formatting
    * Update main.c
    Fixed formatting and indentation
    * Update main.c
    Fixed formatting
    * Merge branch 'master' of https://github.com/SRA-VJTI/MARIO
    * merge master branch
    [main.c]
2022-06-16 OLED functionality added for mario (#22)
    * added OLED functionality in servo_set_zero
    * Added OLED functionality in servo sweep
    * Added OLED functionality in servo test webserver
    * Updated sra-board-component submodule
2022-06-17 All required changes for rosserial gripper support (#23)
2023-04-21 Update sumodule sra-board-component to latest version
2023-04-22 Added joint effort ontroller dependency
2023-04-22 Revert "Update sumodule sra-board-component to latest version" (#35)
2023-04-22 Update submodule sra-board-component to latest version (#36)
    * Update submodule sra-board-component to latest version
    * Update code related to oled according to latest oled.h
    * Removed sdkconfig
2023-04-28 Added DH-Parameters and Kinematics assignment activity
2026-04-14 MARIO Update 2026 v2.4 (#92)
    * added STL
    * STL meter files
    * added mujoco compatibility
    * added README for mujoco sim
    * Updated Config
    * added mario pick_place controller
    * Updated README
    * created src for ease of build
    * submodule update sra-board-components
    * fixing rviz.py for exchanged shoulder and elbow joints
    * typo fix
    * added velocity controlled kv to make motors not oscillate during fk simulation in mujoco
    * update rviz.py to match teleop of that of gazebo
    * fix the joint naming in forward_kinematics.py
    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
    [base_link.STL, claw_left.STL, claw_right.STL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]
2026-04-16 refactor servo configuration to comply new servo driver (#95)
    * refactor servo configuration to comply new driver
    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

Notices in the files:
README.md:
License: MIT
